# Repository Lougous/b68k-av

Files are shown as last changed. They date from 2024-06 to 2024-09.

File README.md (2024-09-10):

# Overview

This board provides audio and video capabilities to the b68k computer. Main components:
* CPLD for local bus decoding and FPGA configuration
* [flex FPGA](/doc/flex.md)
* SRAM 16-bits, 256kiB or 512 kiB
* video RAMDAC
* OPL2 audio chip

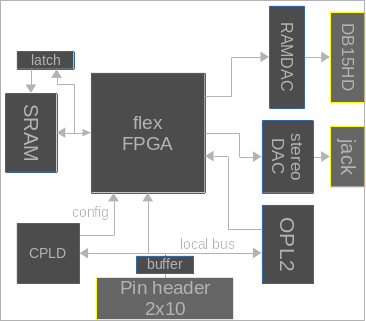
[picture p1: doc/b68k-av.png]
b68k-av block diagram


external interfaces: video (VGA, DIN 15 pins) and audio (3.5mm jack) 

# Memory mapping

The AVMGR CPLD decodes local bus accesses to address itself, the RAMDAC, the OPL2 or the flex FPGA.

| address range | size | memory area |
|:---:|:---:|:-----:|
| 00000h  - 0007Fh  | 128B | AVMGR registers. address bit 0 is ignored |
| 00080h  - 000FFh  | 128B | flex registers |
| 00100h  - 0017Fh  | 128B | RAMDAC registers. address bit 0 is ignored |
| 00180h  - 001FFh  | 128B | OPL2 registers. address bit 0 is ignored |
| 00200h  - 07FFFh  | 512B*63 | mirrors x63 address range 000h-1FFh |
| 08000h -  0FFFFh  | 32kiB | SRAM access (upper 32kiB, banking through flex register) |
| 10000h -  1FFFFh  | 64kiB | SRAM access (banking through flex register) |

## AVMGR registers

These registers provide an interface to configure the flex FPGA. Address bit 0 is ignored, so that odd address target the same register as at even address.

| address offset | name | description |
|:---:|:---:|:-----
| 00000h | cfgnsts | bit 0: (r) flex nSTATUS signal<br>bit 1: (r) flex CONF_DONE signal<br>bit 6: (rw) flex nCONFIG signal<br>bit 7: (rw) flex reset signal (active low) |
| 00002h | dat | bit 0: (rw) flex DAT0 signal<br>When this register is written, the flex DAT0 signal is driven and a pulse is generated on DCLK |
| 00004h | dbg0 | spare register for debug purpose |
| 00006h | dbg1 | spare register for debug purpose |

These registers mirror every 8 bytes.

## OPL2 registers

Provide access to the 2 OPL2 registers. Address bit 0 is ignored, so that odd address target the same register as at even address.

| address offset | name | description |
|:---:|:---:|:-----
| 00000h | regad | OPL2 Address (write) and status (read) register |
| 00002h | regdt | OPL2 Data register |

## RAMDAC registers

Provide access to the RAMDAC registers (Bt476 / IMS G176 or compatible). Address bit 0 is ignored, so that odd address target the same register as at even address.

| address offset | name | description |
|:---:|:---:|:-----
| 00000h | ad_write | Address Register (RAM Write Mode) |
| 00002h | color | Color Palette RAM |
| 00004h | mask | Pixel read Mask Register |
| 00006h | ad_read | Address Register (RAM Read Mode) |

## flex registers

See [flex FPGA](/doc/flex.md) documentation.

# BOM

| Reference  | Part |
|:---:|:---:|
| RN1 | not populated |
| U1 | 74F245 |
| U2 | EPM7064SLC44-10 |
| U3 | MPC6002 |
| U4 | LM337 |
| U6 | EPF10K10LC84-4 |
| U7, U8 | 74F373 |
| U11 | YM3812 (OPL2) |
| U12 | KDA0476BCN-66 |
| D5 | BAT48 (shottky) |
| X1 or X3 | 25-MHz |

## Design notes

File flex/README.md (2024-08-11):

### tools
The latest Quartus version that supports FLEX devices is 9.0 SP2. Not available for download on intel servers any more, here is a link to archive.org:
https://archive.org/details/90sp-2-quartus-free_202310

On linux, depending on distribution/version the use with wine is uncertain ... sometimes quartus can install and run properly, sometimes intall freezes at final stage and GUI cannot run. So far compilation is still possible with command line - see flow.sh script

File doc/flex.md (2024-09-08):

The flex FPGA architecture is depicted hereafter:
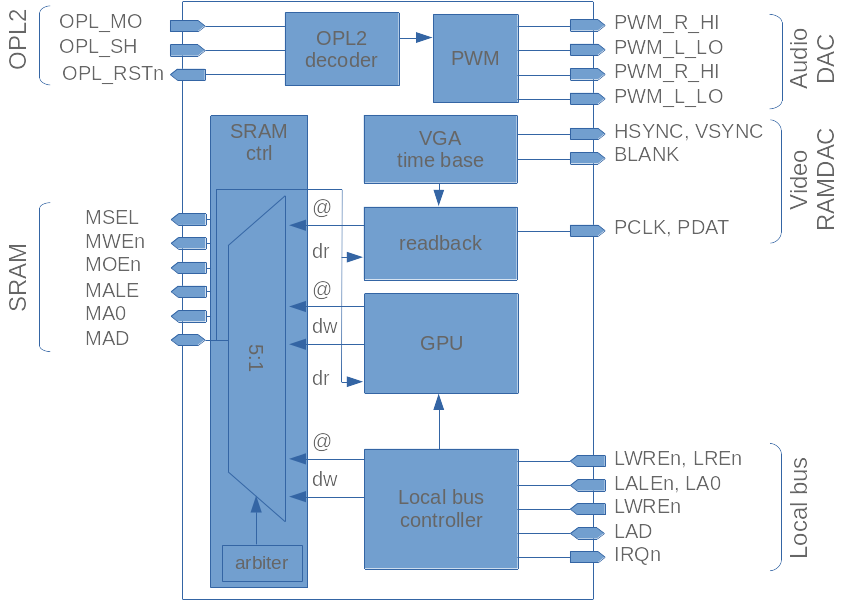
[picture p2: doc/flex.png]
flex FPGA block diagram


# local bus

## Read operations

All read accesses access a single status register:

| address offset | name | description |
|:---:|:---:|:-----:|
| any | status | bit 0: interrupt enable (active high)<br>bit 1: pending interrupt (active high)<br>bits 6..4: SRAM bank (8 banks x 64kiB = 512kiB)<br>7: GPU busy (active high) |

## Write operations (registers)

| address offset | name | description |
|:---:|:---:|:-----:|
| 00080h | itcgf  | bit 0: interrupt enable (active high)<br>bit 1: pending interrupt acknowlege (when written as 1) |
| 00081h | bank | bits 6..4: SRAM access bank (8 banks x 64kiB = 512kiB) |
| 00082h | - | spare |
| 00083h | - | spare |
| 00084h | gpu0 | stop current buffer execution, if so, then set GPU command buffer address bits 8..1 |
| 00085h | gpu1 | set GPU command buffer address bits 16..9, then start command buffer execution |
| 00086h | - | spare |
| 00087h | - | spare |

## Write operations (SRAM)

Write access to SRAM is controlled by the ''bank'' register, that defines which 64kiB section of the SRAM targets the write access into the address ranges listed below:

| address range | size | memory area |
|:---:|:---:|:-----:|
| 08000h -  0FFFFh  | 32kiB  | SRAM access (upper 32kiB of current bank) |
| 10000h -  1FFFFh  | 64kiB  | SRAM access (full bank) |

# GPU

The GPU ables to perform basic 2D memory bloc move operations:
* READ operation: from SRAM to internal scratchpad memory (256 bytes, can be split in 4 banks of 64 bytes)
* WRITE operation: from internal scratchpad memory to SRAM.

READ/WRITE operations purpose is to draw 2D sprites. Sprites are 4-bits per pixels; as pixels in frame buffer are 8-bits, each sprite pixel is completed with an additional 4-bit value (that can be changed for each WRITE operation).

The sprite pixel value 0000b may be optionnaly considered as masked (not written).

Each operation can handle block size of 1 to 16 lines by 1 to 16 words wide, though multiple operations can be used to manage bigger sprites.

GPU commands are a list of 16-bits words, stored into lower 128-kiB in SRAM (00000h to 1FFFEh). Buffer must be 16-bits aligned.

To use the GPU, the usual sequence is:
* load/update graphic data to SRAM
* load/update command list in SRAM
* last command in the list must have the S flag to stop properly (see table below)
* start command list execution (registers ''gpu0''/''gpu1'')

GPU commands also able:
* to change the frame buffer address used by the video readback
* to change the frame buffer format used by the video readback
* to synchronize a command to the vertical refresh

<table>
  <thead>
    <tr>
      <th>15</th><th>14</th><th>13</th><th>12</th><th>11</th><th>10</th><th>9</th><th>8</th>
      <th>7</th><th>6</th><th>5</th><th>4</th><th>3</th><th>2</th><th>1</th><th>0</th>
    </tr>
  </thead>
  <tbody>
    <tr>
      <td>0</td><td colspan=15>ADDR(14:0)</td>
    </tr>
    <tr>
      <td>1</td><td>0</td><td>-</td><td colspan=4>ADDR(18:15)</td><td>S</td><td colspan=4>HEIGHT(3:0)</td><td>F</td><td>LR</td><td>LP</td><td>WS</td>
    </tr>
    <tr>
      <td>1</td><td>1</td><td>-</td><td colspan=4>WIDTH(3:0)</td><td>RW</td><td>KY</td><td>-</td><td colspan=2>BK(1:0)</td><td colspan=4>LUT(3:0)</td>
    </tr>
  </tbody>
</table>

* ADDR:   SRAM address to read/write, or to set as frame buffer start address
* S:      stop display list execution when set
* F:      set frame buffer address/attributes when set
* LR:     Low res mode (validated by F)
* LP:     LUT in hi res mode (validated by F)
* WS:     when set with S, wait for next vertical synchro then resume command execution
* HEIGHT: pixel block height (line number, minus 1)
* WIDTH:  pixel block width (word number, minus 1)
* LUT:    pixel byte bits(7:4) for write (4-bits to 8-bits expansion)
* BK:     256 bytes scratchpad start address MSBs (00h, 40h, 80h, C0h)
* KY:     enable transparency during write with color key 0000b
* RW:     transfer direction: 0 for VRAM to scratchpad, 1 for scratchpad to VRAM

# video time base

The video time base generates video timing in respect to VGA video format to sequence the video readback operations.

# video readback

This function reads a frame buffer at a given start address in SRAM and provides pixel to the RAMDAC.

## pixel addressing

The start address may be changed through GPU command, though the new address will be considered at the next start of frame. Any start address in the two pages listed below can be used, but these rules apply:
* during horizontal pixel walk, the address 9 least significant bits only are incremented (within a 512 bytes segment)
* during vertical pixel walk, start address of line N+1 is start address of line N + 512 bytes, but rolls over within the page

These two rules ease the implementation of scrolling frame buffer content in both axis.

| address range | size | memory area |
|:---:|:---:|:-----:|
| 00000h  - 1FFFFh  | 128kiB | not usable for readback |
| 20000h  - 3FFFFh  | 128kiB | page #0 |
| 40000h  - 5FFFFh  | 128kiB | not usable for readback |
| 60000h  - 7FFFFh  | 128kiB | page #1 |

## pixel format

The readback supports 2 modes:
* low resolution mode; pixels are replicated so that an actual resolution of 320x240 pixels is used, yet still with a VGA (640x480) video timing. Each pixel is an 8-bits value that is used as an index into the color lookup table managed by the RAMDAC chip.
* high resolution mode; based on the 320x240x8-bits defined below, each 8-bit pixel is
  * if pixel MSB (bit 7) is set to zero, no change with low resolution mode (except that color index restricts to range 0..127)
  * if pixel MSB (bit 7) is set to one, the pixel is to be considered as a 2x2 pixel tile, thus possibly achieving an actual resolution of 640x480 pixels. Bits 3..0 provide a value for each pixel in the tile; bits 6..4 is used to form the 8-bits color index as detailed hereafter, together with pixel odd/even position over X and Y axis, as well as an additional LP bit (see GPU)

high resolution pixel expansion, upper-left pixel:
<table>
  <thead>
    <tr>
      <th>7</th><th>6</th><th>5</th><th>4</th><th>3</th><th>2</th><th>1</th><th>0</th>
    </tr>
  </thead>
  <tbody>
    <tr>
      <td>1</td><td>LP</td><td colspan=3>bits 6..4</td><td>0</td><td>0</td><td>bit 0</td>
    </tr>
  </tbody>
</table>

high resolution pixel expansion, upper-right pixel:
<table>
  <thead>
    <tr>
      <th>7</th><th>6</th><th>5</th><th>4</th><th>3</th><th>2</th><th>1</th><th>0</th>
    </tr>
  </thead>
  <tbody>
    <tr>
      <td>1</td><td>LP</td><td colspan=3>bits 6..4</td><td>0</td><td>1</td><td>bit 1</td>
    </tr>
  </tbody>
</table>

high resolution pixel expansion, lower-left pixel:
<table>
  <thead>
    <tr>
      <th>7</th><th>6</th><th>5</th><th>4</th><th>3</th><th>2</th><th>1</th><th>0</th>
    </tr>
  </thead>
  <tbody>
    <tr>
      <td>1</td><td>LP</td><td colspan=3>bits 6..4</td><td>1</td><td>0</td><td>bit 2</td>
    </tr>
  </tbody>
</table>

high resolution pixel expansion, lower-right pixel:
<table>
  <thead>
    <tr>
      <th>7</th><th>6</th><th>5</th><th>4</th><th>3</th><th>2</th><th>1</th><th>0</th>
    </tr>
  </thead>
  <tbody>
    <tr>
      <td>1</td><td>LP</td><td colspan=3>bits 6..4</td><td>1</td><td>1</td><td>bit 3</td>
    </tr>
  </tbody>
</table>

# SRAM controller

Grants access to SRAM to (in priority order):
* readback (read only)
* local bus (write only)
* GPU (read / write)

# Audio

The flex FPGA decodes OPL2 output and generates a dual level PWM (6-bits x2, 12-bits precision in total). See ''audio_out_pwm_stereo'' sheet in board schematics for further details.

Both left and right channels output the same (OPL2 is mono).

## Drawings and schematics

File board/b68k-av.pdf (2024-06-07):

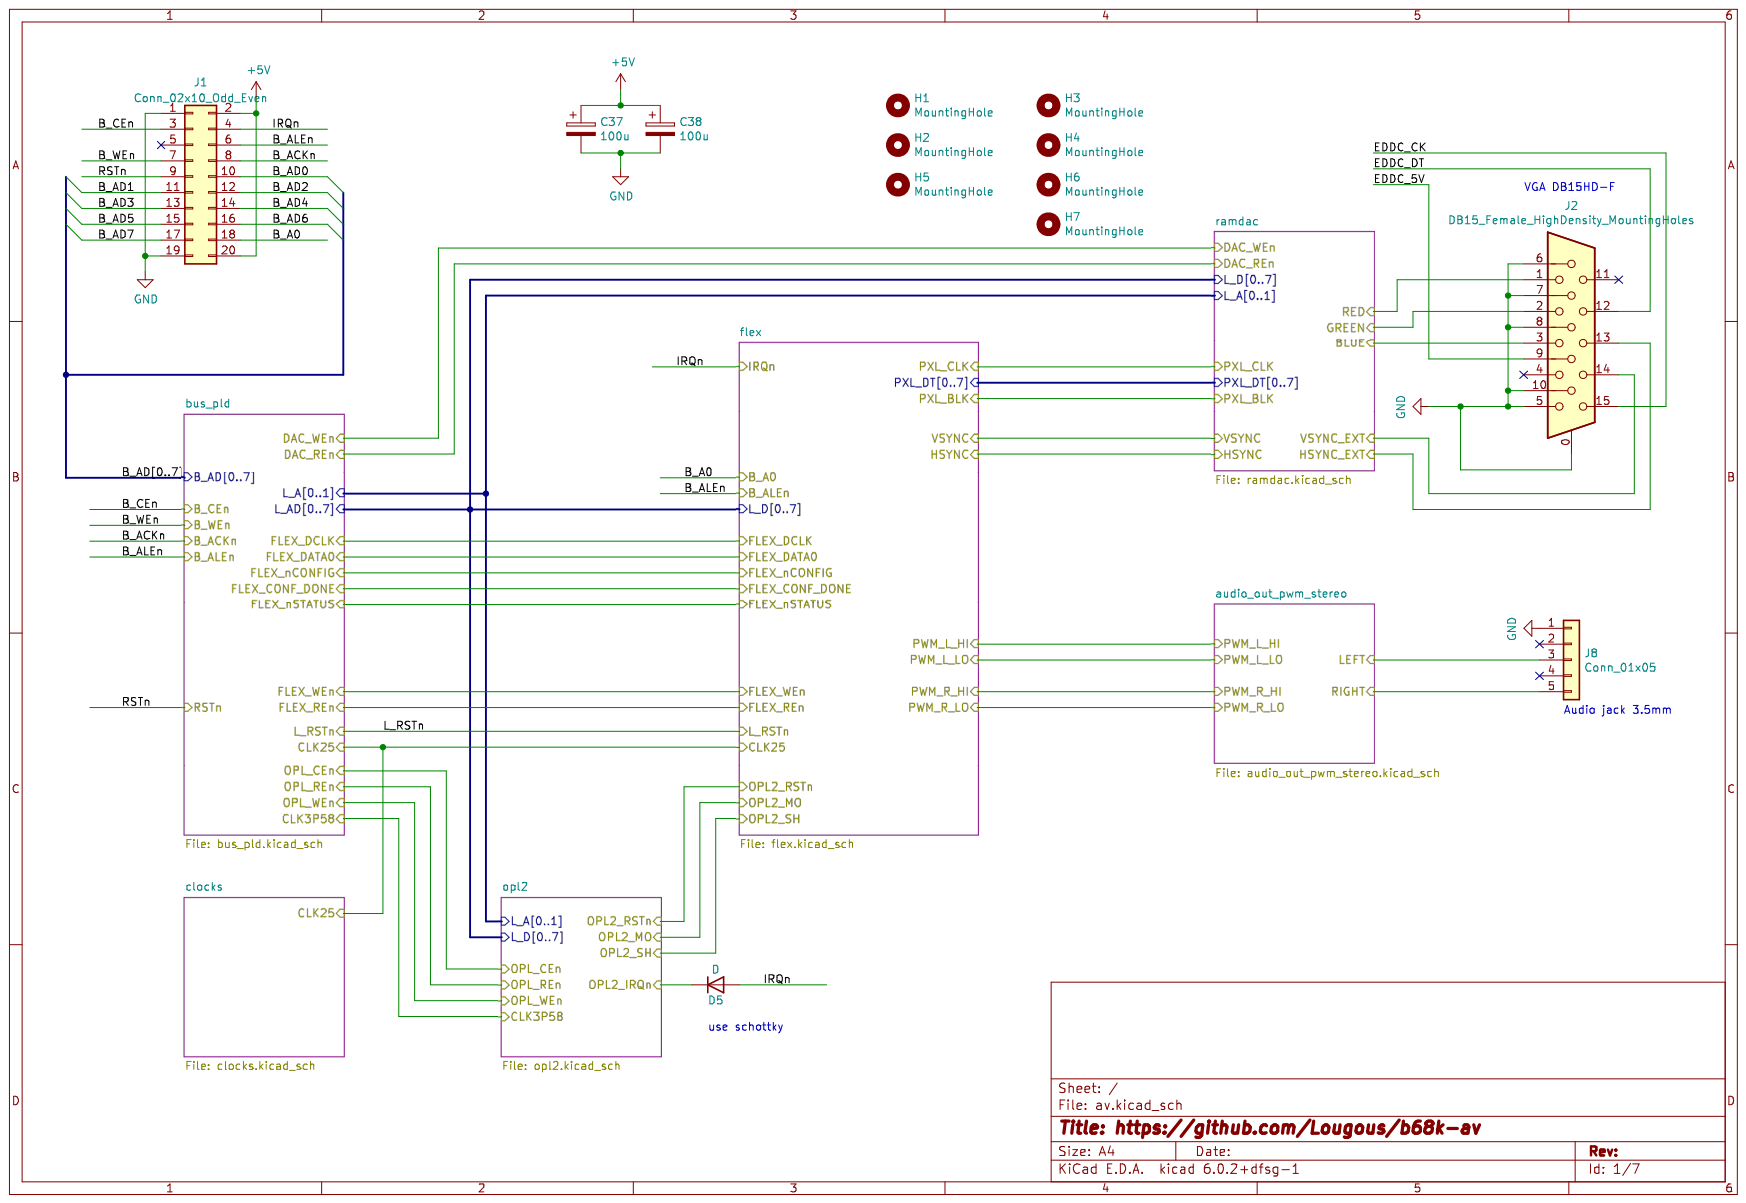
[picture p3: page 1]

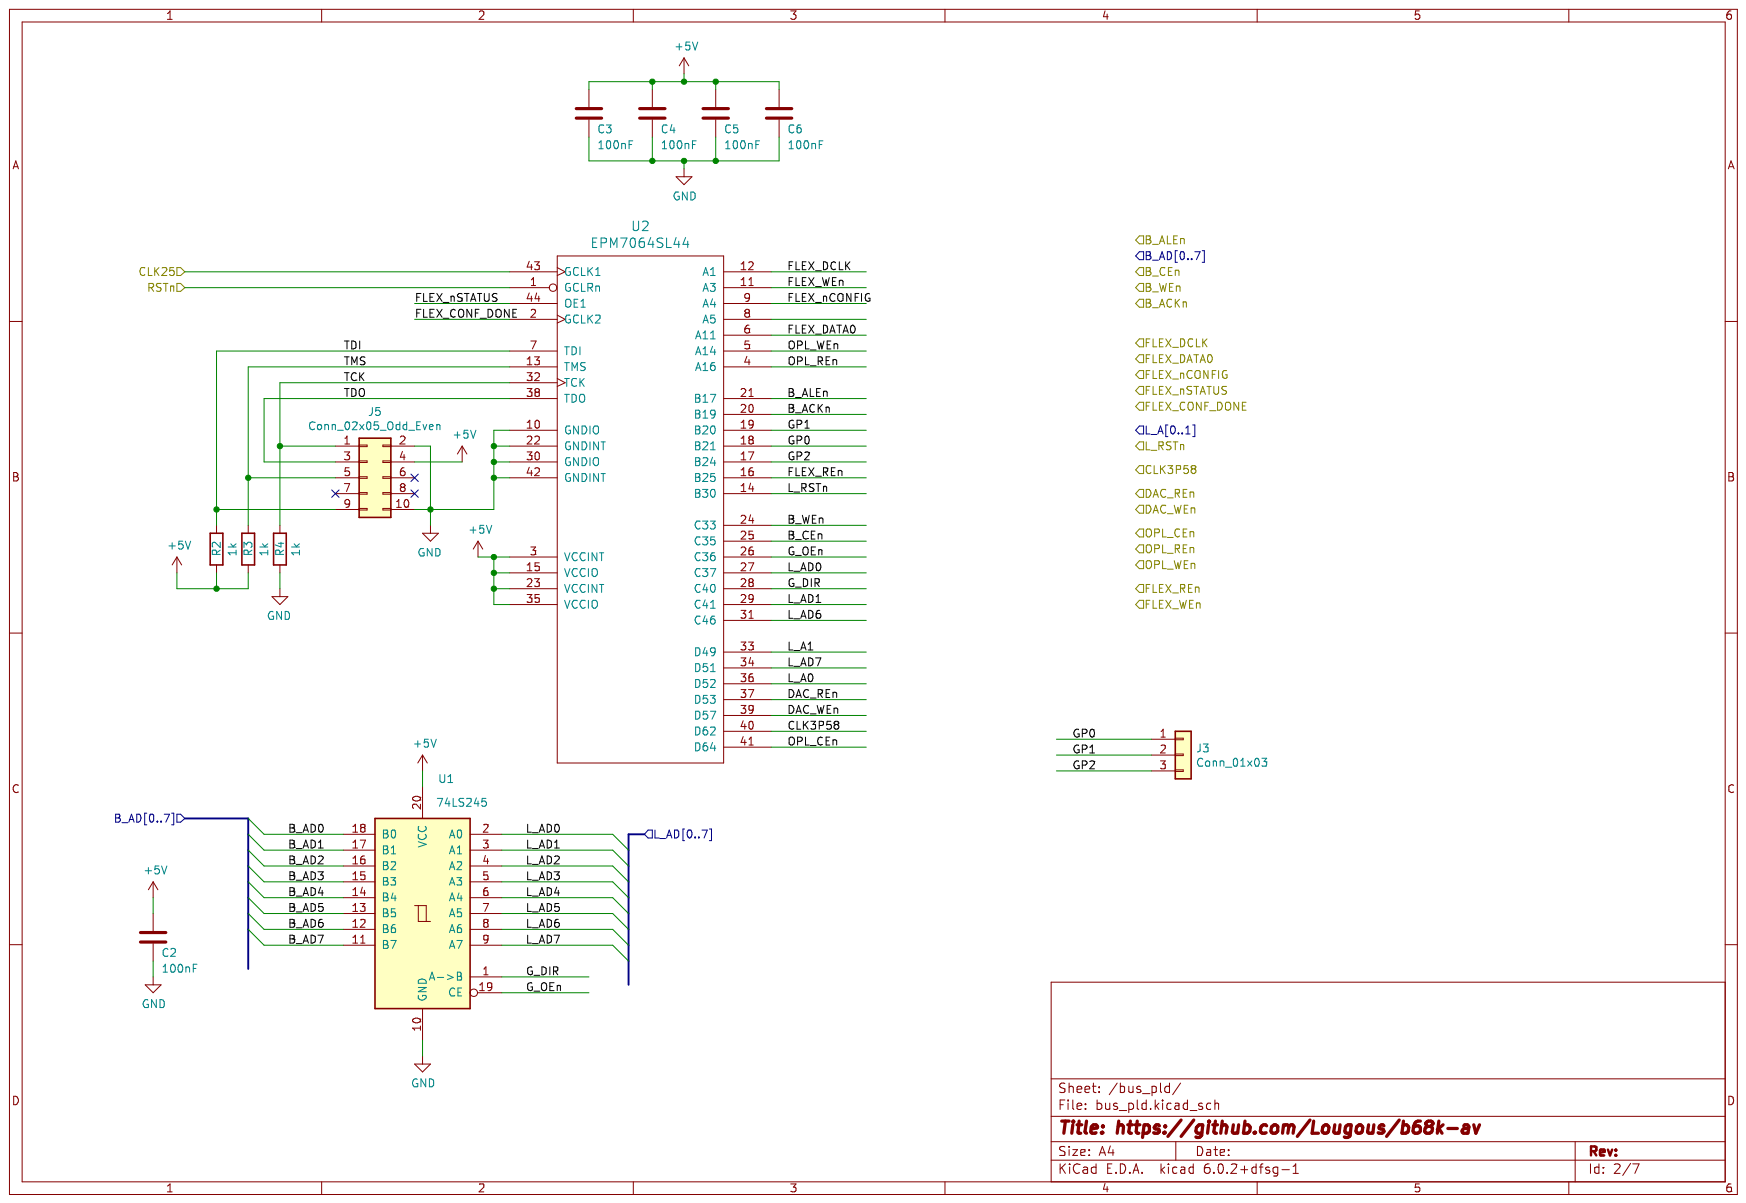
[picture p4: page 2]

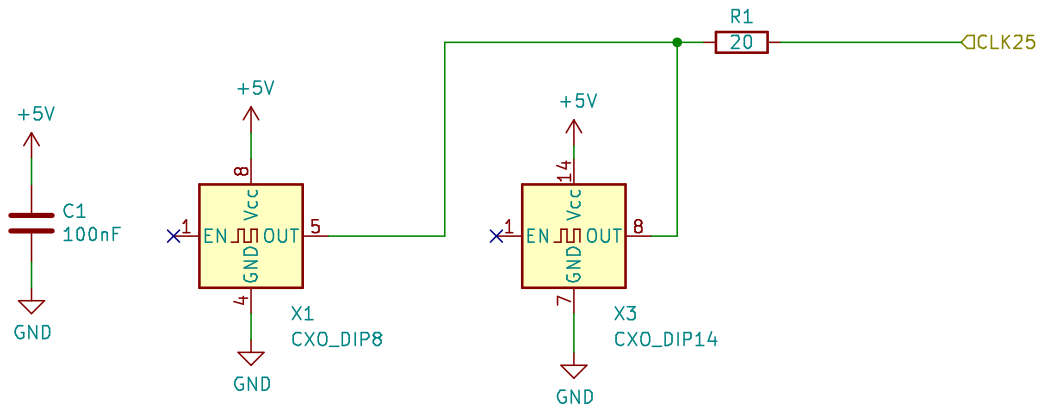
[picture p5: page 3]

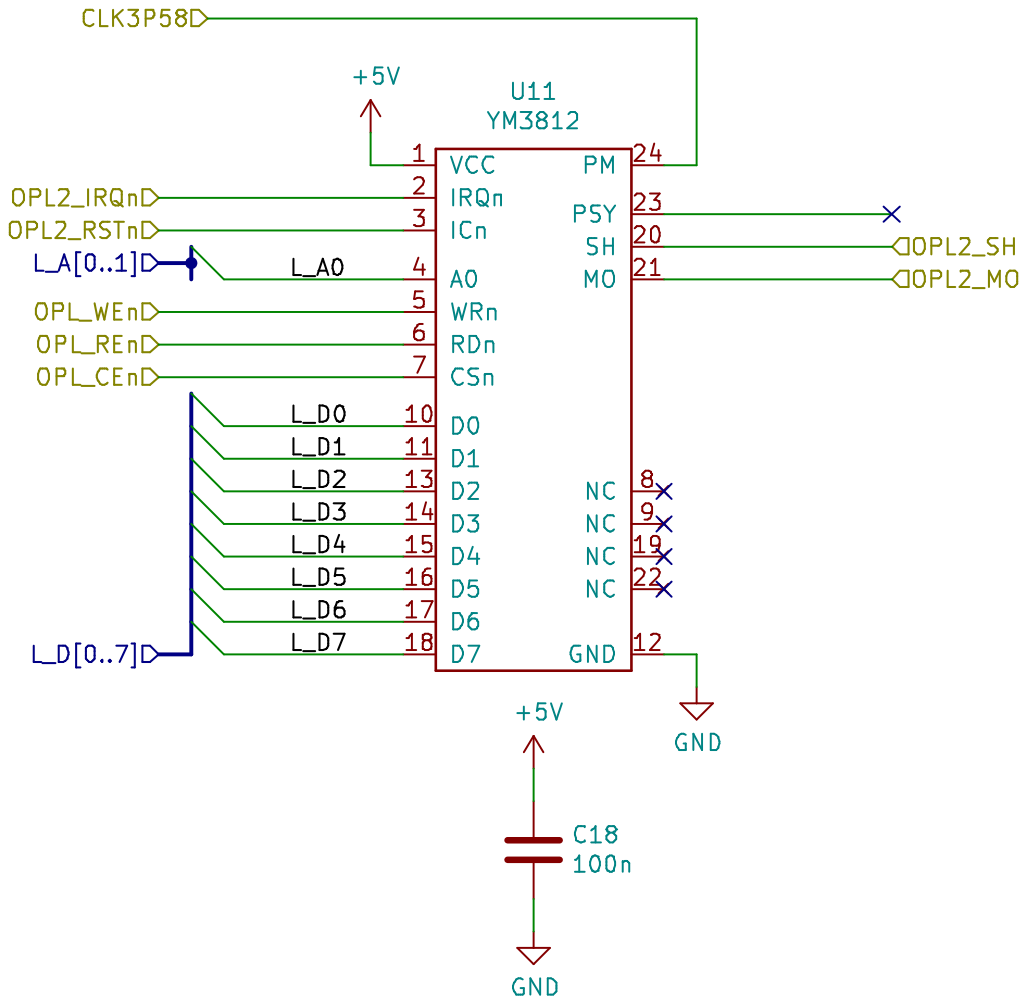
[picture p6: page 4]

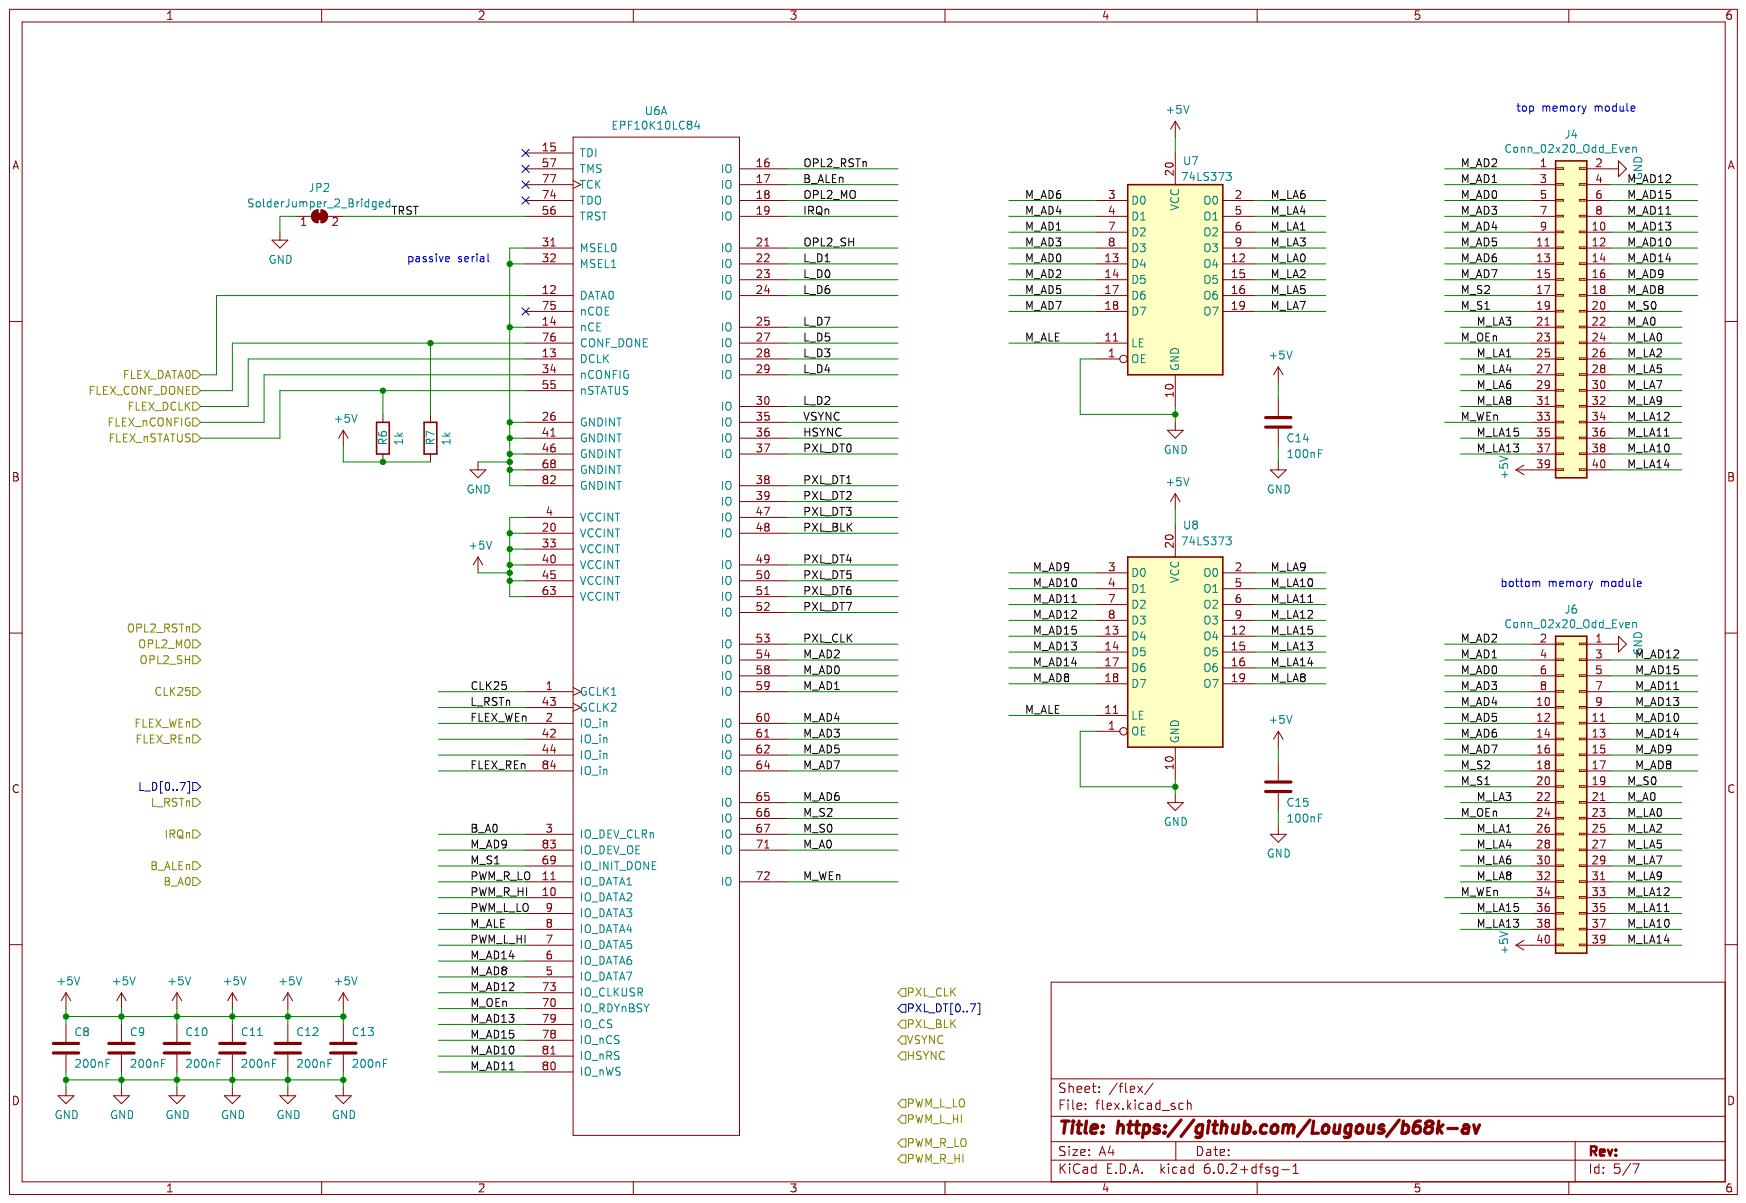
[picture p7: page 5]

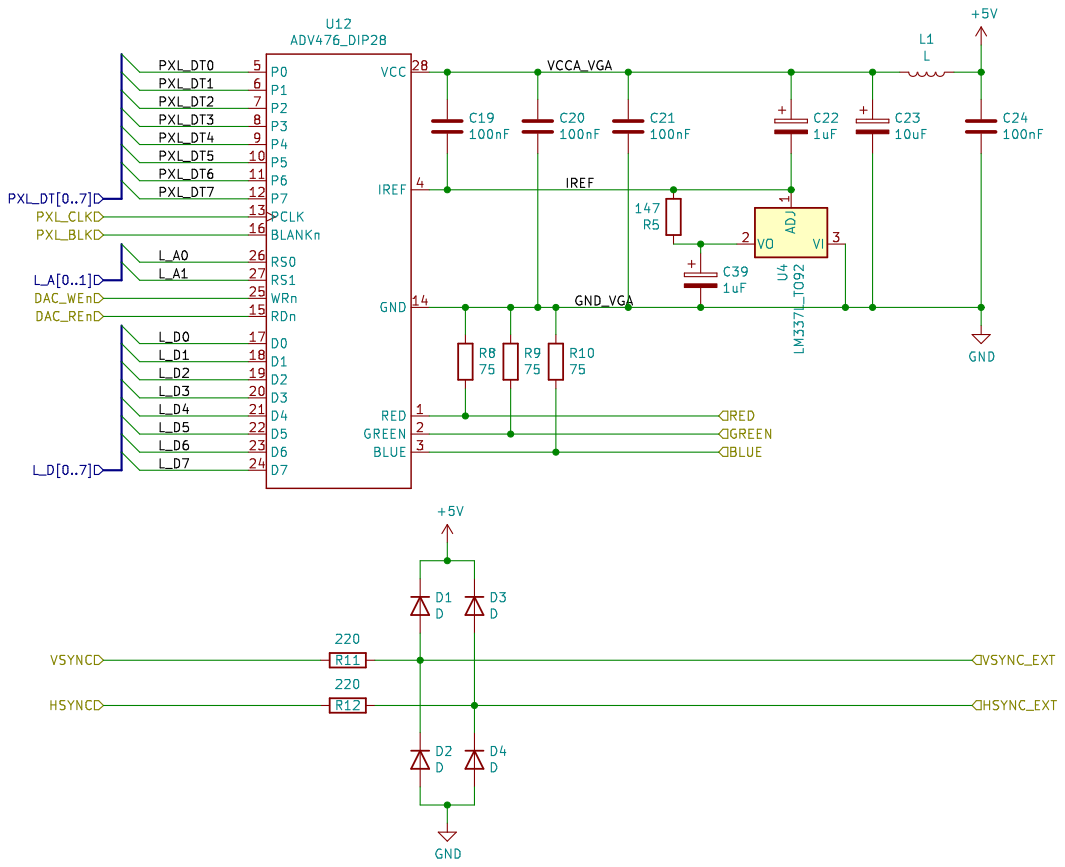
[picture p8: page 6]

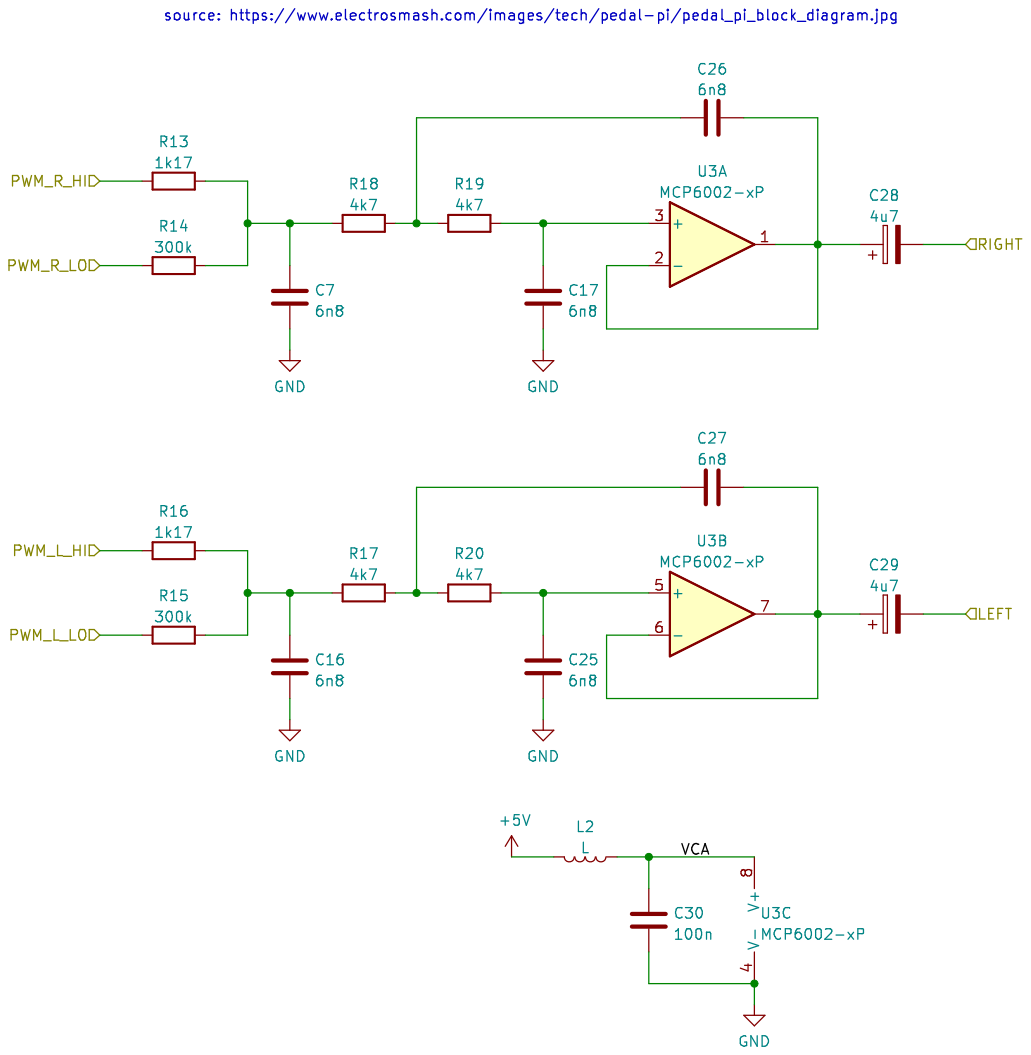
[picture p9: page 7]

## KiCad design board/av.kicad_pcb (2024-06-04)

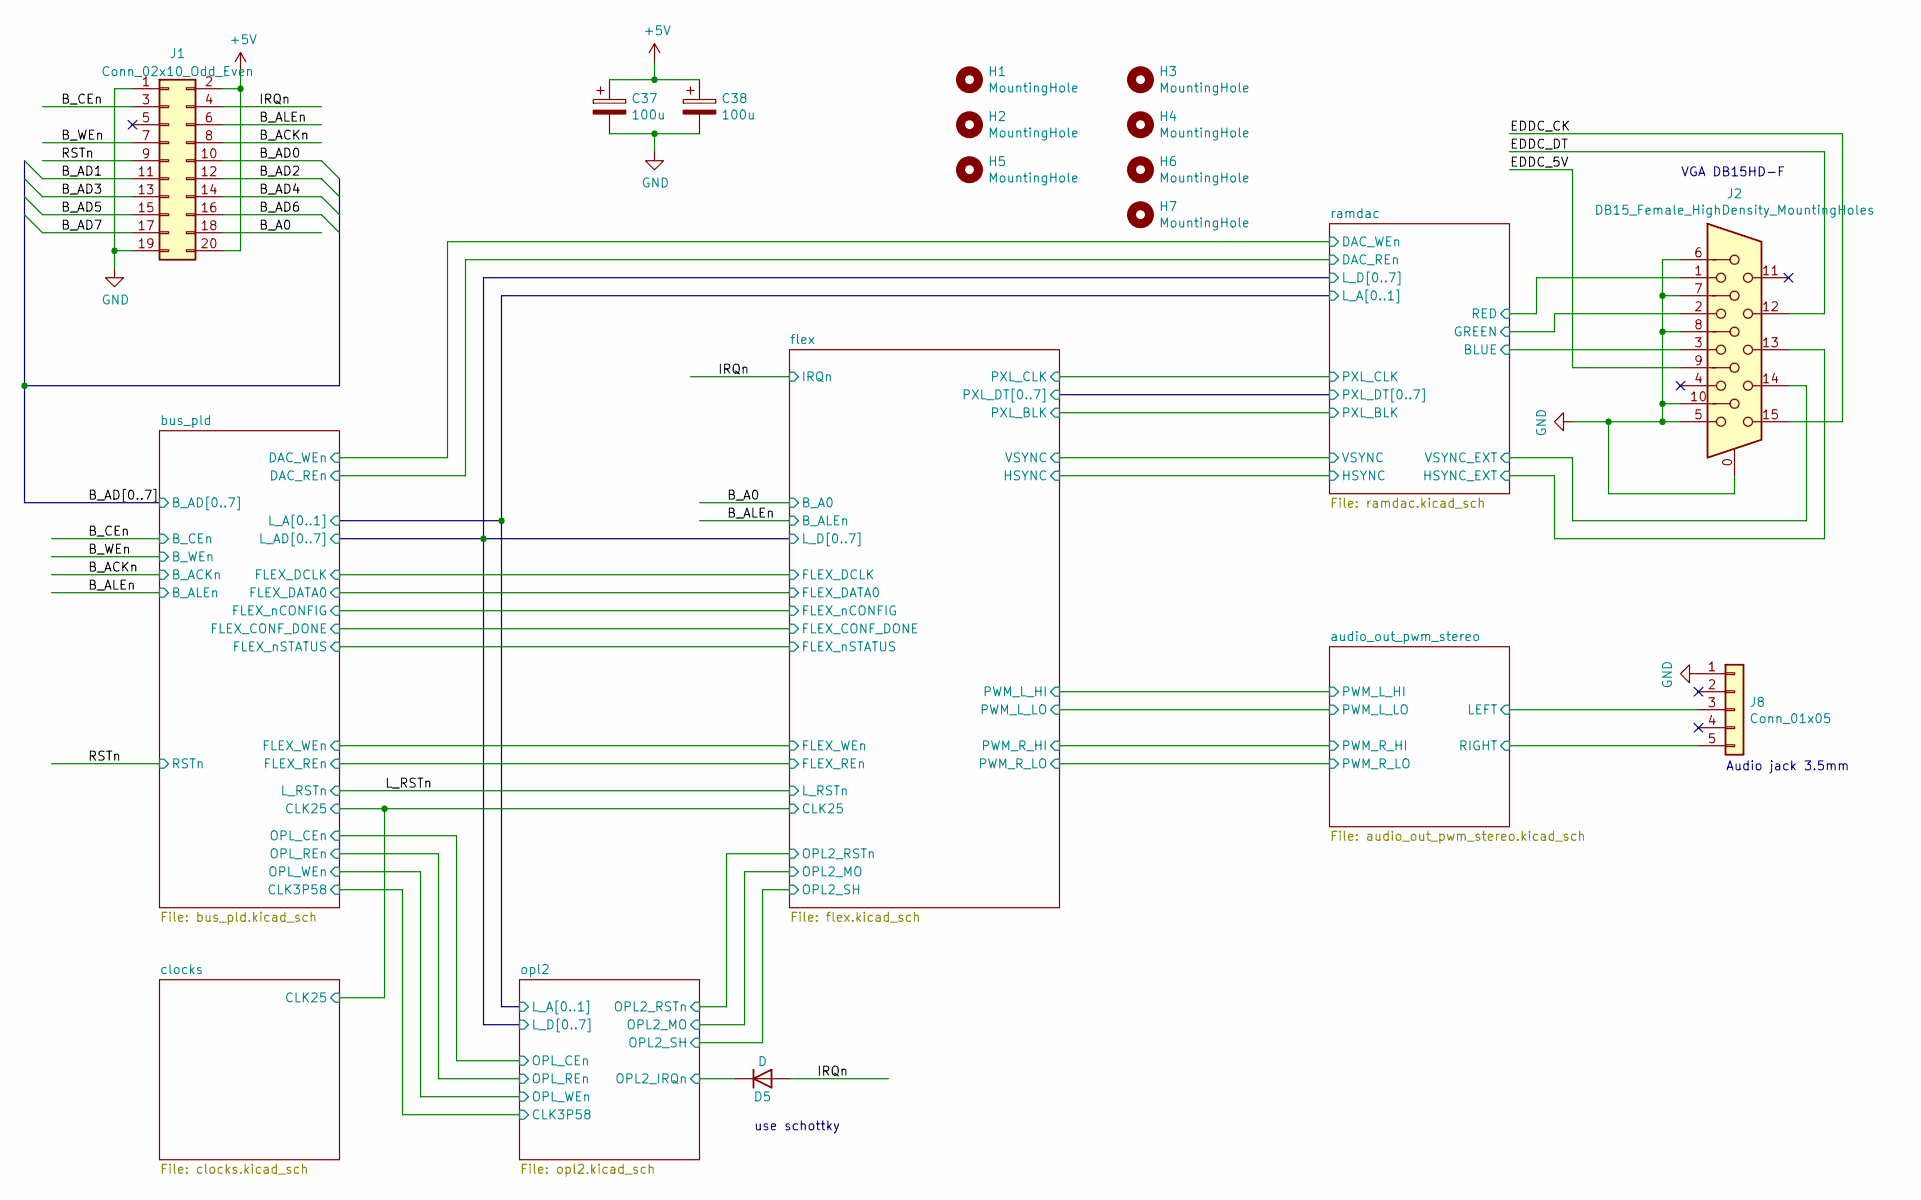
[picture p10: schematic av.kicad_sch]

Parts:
C37, C38: 100u; CP_Radial_D5.0mm_P2.00mm
D5: D; D_DO-34_SOD68_P7.62mm_Horizontal
H1, H2, H3, H4, H5, H6, H7: MountingHole; MountingHole_2.7mm_M2.5_DIN965_Pad
J1: Conn_02x10_Odd_Even; PinHeader_2x10_P2.54mm_Vertical
J2: DB15_Female_HighDensity_MountingHoles; DSUB-15-HD_Female_Horizontal_P2.29x1.98mm_EdgePinOffset3.03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
J8: Conn_01x05; ASJ-5-X_3.5mm_Jack

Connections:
+5V: C37.1, C38.1, J1.2, J1.20; also elsewhere on the board
/B_A0: J1.18; also elsewhere on the board
/B_ACKn: J1.8; also elsewhere on the board
/B_AD0: J1.10; also elsewhere on the board
/B_AD1: J1.11; also elsewhere on the board
/B_AD2: J1.12; also elsewhere on the board
/B_AD3: J1.13; also elsewhere on the board
/B_AD4: J1.14; also elsewhere on the board
/B_AD5: J1.15; also elsewhere on the board
/B_AD6: J1.16; also elsewhere on the board
/B_AD7: J1.17; also elsewhere on the board
/B_ALEn: J1.6; also elsewhere on the board
/B_CEn: J1.3; also elsewhere on the board
/B_WEn: J1.7; also elsewhere on the board
/EDDC_5V: J2.9
/EDDC_CK: J2.15
/EDDC_DT: J2.12
/IRQn: D5.2 (A), J1.4; also elsewhere on the board
/RSTn: J1.9; also elsewhere on the board
/audio_out_pwm_stereo/LEFT: J8.3; also elsewhere on the board
/audio_out_pwm_stereo/RIGHT: J8.5; also elsewhere on the board
/opl2/OPL2_IRQn: D5.1 (K); also elsewhere on the board
/ramdac/BLUE: J2.3; also elsewhere on the board
/ramdac/GREEN: J2.2; also elsewhere on the board
/ramdac/HSYNC_EXT: J2.13; also elsewhere on the board
/ramdac/RED: J2.1; also elsewhere on the board
/ramdac/VSYNC_EXT: J2.14; also elsewhere on the board
GND: C37.2, C38.2, J1.1, J1.19, J2.0, J2.5, J2.6, J2.7, J2.8, J2.10, J8.1; also elsewhere on the board

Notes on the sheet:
Audio jack 3.5mm
use schottky
VGA DB15HD-F

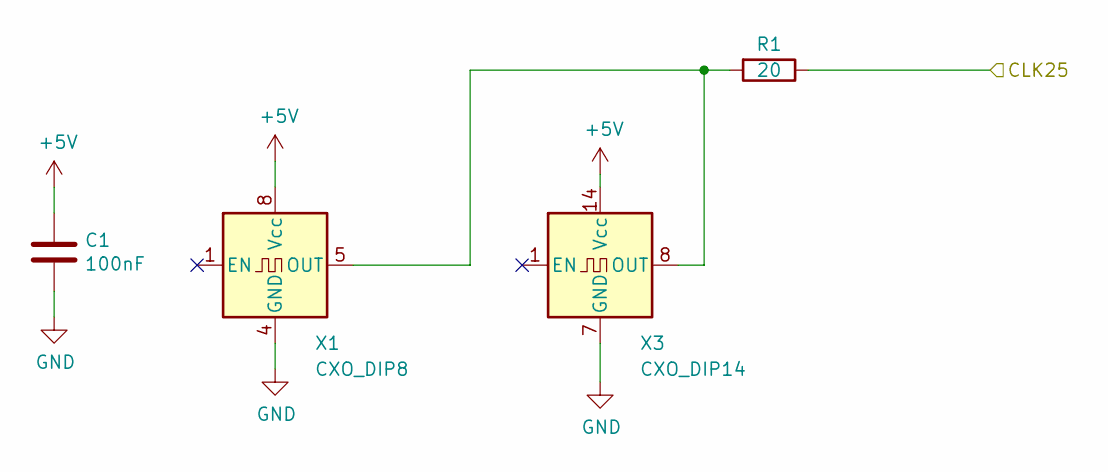
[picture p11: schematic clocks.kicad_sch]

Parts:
C1: 100nF; C_Disc_D4.3mm_W1.9mm_P5.00mm
R1: 20; R_Axial_DIN0204_L3.6mm_D1.6mm_P7.62mm_Horizontal
X1: CXO_DIP8; Oscillator_DIP-8
X3: CXO_DIP14; Oscillator_DIP-14

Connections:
+5V: C1.1, X1.8 (Vcc), X3.14 (Vcc); also elsewhere on the board
/flex/CLK25: R1.1; also elsewhere on the board
GND: C1.2, X1.4 (GND), X3.7 (GND); also elsewhere on the board
unnamed: R1.2, X1.5 (OUT), X3.8 (OUT)

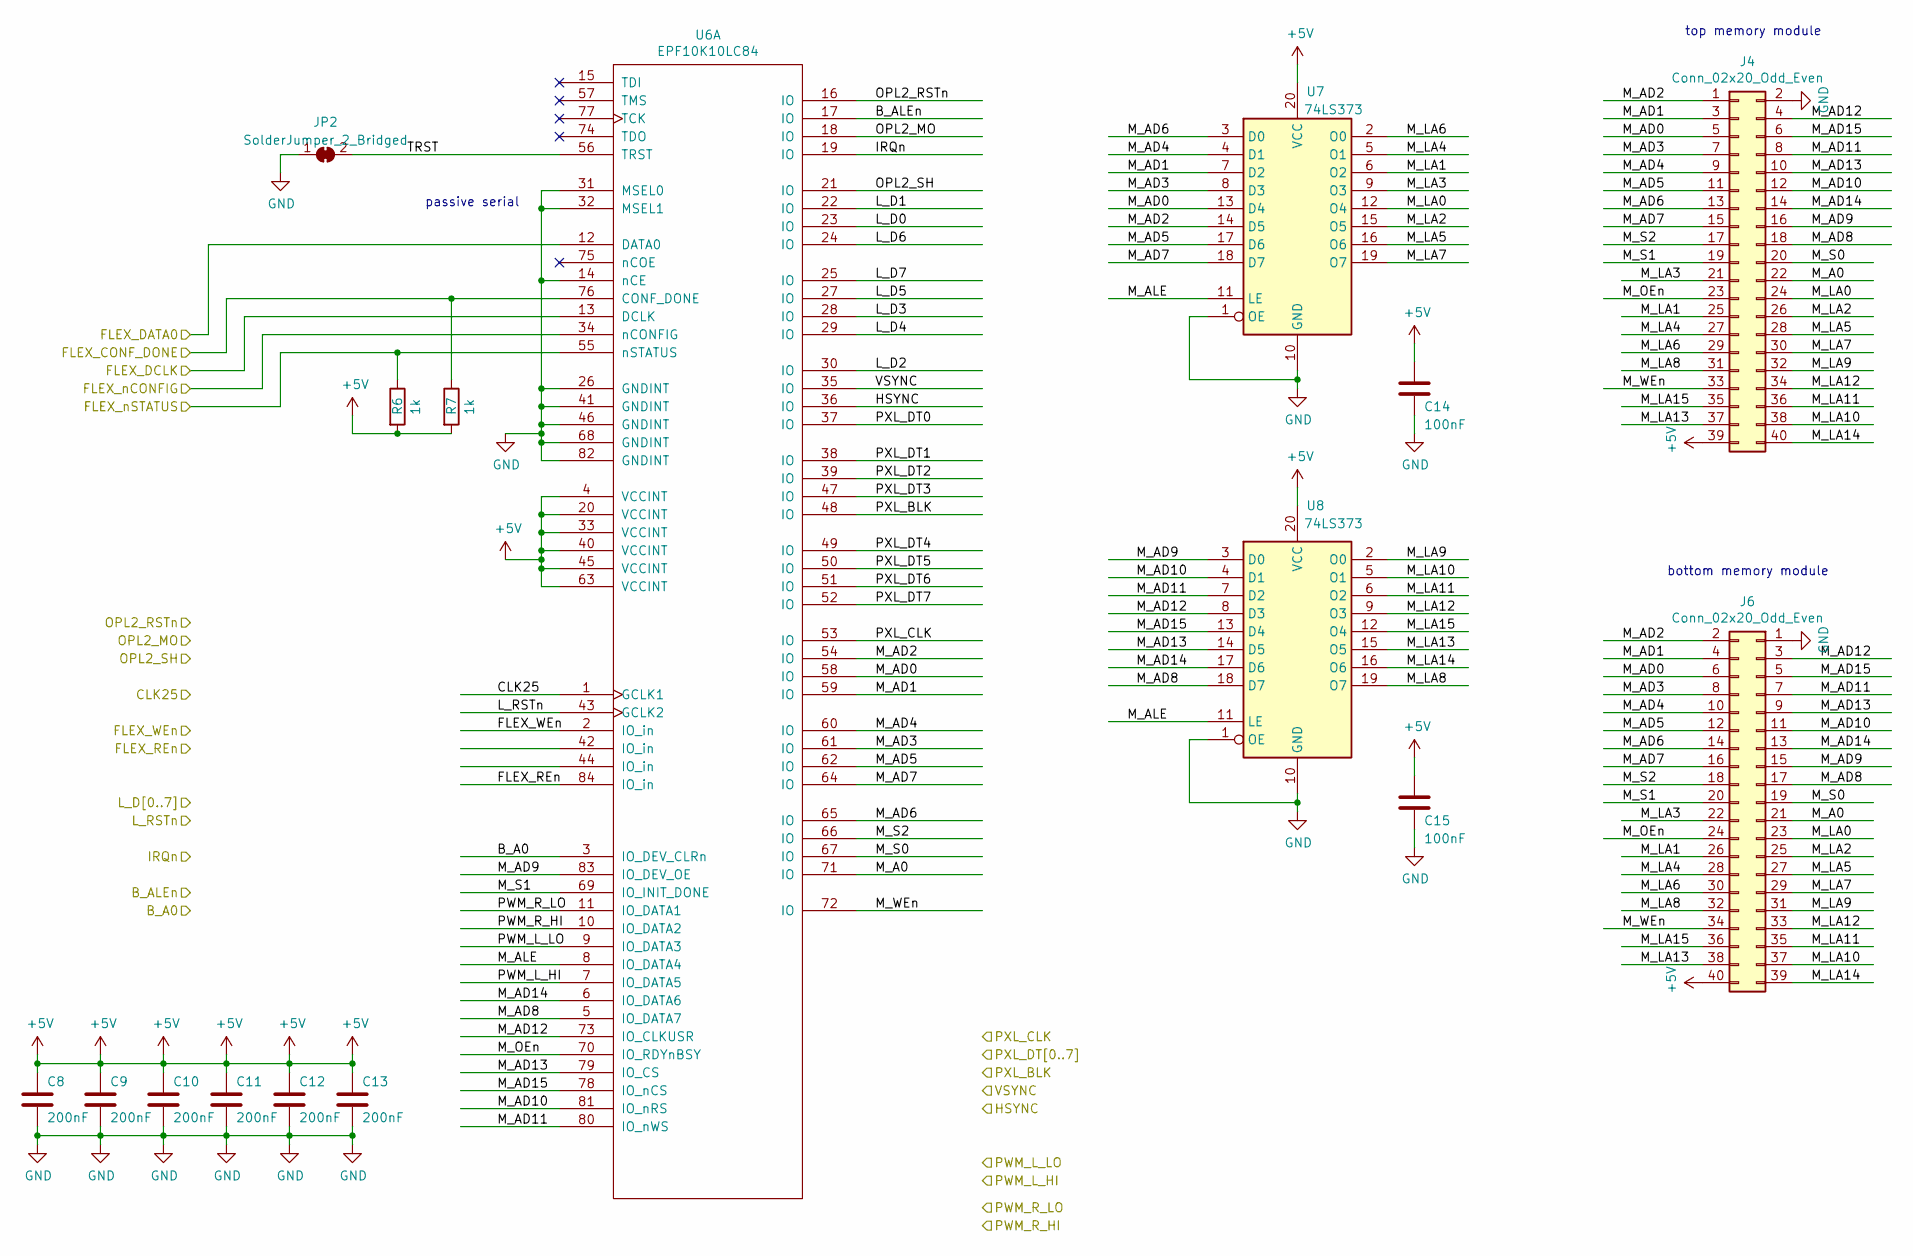
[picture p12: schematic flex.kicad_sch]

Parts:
C8, C9, C10, C11, C12, C13: 200nF; C_Disc_D4.3mm_W1.9mm_P5.00mm
C14, C15: 100nF; C_Disc_D4.3mm_W1.9mm_P5.00mm
J4, J6: Conn_02x20_Odd_Even; PinSocket_2x20_P2.00mm_Vertical_SMD
JP2: SolderJumper_2_Bridged; SolderJumper-2_P1.3mm_Bridged_RoundedPad1.0x1.5mm
R6, R7: 1k; R_Axial_DIN0204_L3.6mm_D1.6mm_P7.62mm_Horizontal
U6: EPF10K10LC84; PLCC-84_THT-Socket
U7, U8: 74LS373; DIP-20_W7.62mm_Socket

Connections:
+5V: C8.1, C9.1, C10.1, C11.1, C12.1, C13.1, C14.1, C15.1, J4.39, J6.40, R6.2, R7.2, U6.4 (VCCINT), U6.20 (VCCINT), U6.33 (VCCINT), U6.40 (VCCINT), U6.45 (VCCINT), U6.63 (VCCINT), U7.20 (VCC), U8.20 (VCC); also elsewhere on the board
/B_A0: U6.3 (IO_DEV_CLRn); also elsewhere on the board
/B_ALEn: U6.17 (IO); also elsewhere on the board
/IRQn: U6.19 (IO); also elsewhere on the board
/L_RSTn: U6.43 (GCLK2); also elsewhere on the board
/bus_pld/FLEX_CONF_DONE: R7.1, U6.76 (CONF_DONE); also elsewhere on the board
/bus_pld/FLEX_DATA0: U6.12 (DATA0); also elsewhere on the board
/bus_pld/FLEX_DCLK: U6.13 (DCLK); also elsewhere on the board
/bus_pld/FLEX_REn: U6.84 (IO_in); also elsewhere on the board
/bus_pld/FLEX_WEn: U6.2 (IO_in); also elsewhere on the board
/bus_pld/FLEX_nCONFIG: U6.34 (nCONFIG); also elsewhere on the board
/bus_pld/FLEX_nSTATUS: R6.1, U6.55 (nSTATUS); also elsewhere on the board
/bus_pld/L_AD0: U6.23 (IO); also elsewhere on the board
/bus_pld/L_AD1: U6.22 (IO); also elsewhere on the board
/bus_pld/L_AD2: U6.30 (IO); also elsewhere on the board
/bus_pld/L_AD3: U6.28 (IO); also elsewhere on the board
/bus_pld/L_AD4: U6.29 (IO); also elsewhere on the board
/bus_pld/L_AD5: U6.27 (IO); also elsewhere on the board
/bus_pld/L_AD6: U6.24 (IO); also elsewhere on the board
/bus_pld/L_AD7: U6.25 (IO); also elsewhere on the board
/flex/CLK25: U6.1 (GCLK1); also elsewhere on the board
/flex/HSYNC: U6.36 (IO); also elsewhere on the board
/flex/M_A0: J4.22, J6.21, U6.71 (IO)
/flex/M_AD0: J4.5, J6.6, U6.58 (IO), U7.13 (D4)
/flex/M_AD1: J4.3, J6.4, U6.59 (IO), U7.7 (D2)
/flex/M_AD2: J4.1, J6.2, U6.54 (IO), U7.14 (D5)
/flex/M_AD3: J4.7, J6.8, U6.61 (IO), U7.8 (D3)
/flex/M_AD4: J4.9, J6.10, U6.60 (IO), U7.4 (D1)
/flex/M_AD5: J4.11, J6.12, U6.62 (IO), U7.17 (D6)
/flex/M_AD6: J4.13, J6.14, U6.65 (IO), U7.3 (D0)
/flex/M_AD7: J4.15, J6.16, U6.64 (IO), U7.18 (D7)
/flex/M_AD8: J4.18, J6.17, U6.5 (IO_DATA7), U8.18 (D7)
/flex/M_AD9: J4.16, J6.15, U6.83 (IO_DEV_OE), U8.3 (D0)
/flex/M_AD10: J4.12, J6.11, U6.81 (IO_nRS), U8.4 (D1)
/flex/M_AD11: J4.8, J6.7, U6.80 (IO_nWS), U8.7 (D2)
/flex/M_AD12: J4.4, J6.3, U6.73 (IO_CLKUSR), U8.8 (D3)
/flex/M_AD13: J4.10, J6.9, U6.79 (IO_CS), U8.14 (D5)
/flex/M_AD14: J4.14, J6.13, U6.6 (IO_DATA6), U8.17 (D6)
/flex/M_AD15: J4.6, J6.5, U6.78 (IO_nCS), U8.13 (D4)
/flex/M_ALE: U6.8 (IO_DATA4), U7.11 (LE), U8.11 (LE)
/flex/M_LA0: J4.24, J6.23, U7.12 (O4)
/flex/M_LA1: J4.25, J6.26, U7.6 (O2)
/flex/M_LA2: J4.26, J6.25, U7.15 (O5)
/flex/M_LA3: J4.21, J6.22, U7.9 (O3)
/flex/M_LA4: J4.27, J6.28, U7.5 (O1)
/flex/M_LA5: J4.28, J6.27, U7.16 (O6)
/flex/M_LA6: J4.29, J6.30, U7.2 (O0)
/flex/M_LA7: J4.30, J6.29, U7.19 (O7)
/flex/M_LA8: J4.31, J6.32, U8.19 (O7)
/flex/M_LA9: J4.32, J6.31, U8.2 (O0)
/flex/M_LA10: J4.38, J6.37, U8.5 (O1)
/flex/M_LA11: J4.36, J6.35, U8.6 (O2)
/flex/M_LA12: J4.34, J6.33, U8.9 (O3)
/flex/M_LA13: J4.37, J6.38, U8.15 (O5)
/flex/M_LA14: J4.40, J6.39, U8.16 (O6)
/flex/M_LA15: J4.35, J6.36, U8.12 (O4)
/flex/M_OEn: J4.23, J6.24, U6.70 (IO_RDYnBSY)
/flex/M_S0: J4.20, J6.19, U6.67 (IO)
/flex/M_S1: J4.19, J6.20, U6.69 (IO_INIT_DONE)
/flex/M_S2: J4.17, J6.18, U6.66 (IO)
/flex/M_WEn: J4.33, J6.34, U6.72 (IO)
/flex/OPL2_MO: U6.18 (IO); also elsewhere on the board
/flex/OPL2_RSTn: U6.16 (IO); also elsewhere on the board
/flex/OPL2_SH: U6.21 (IO); also elsewhere on the board
/flex/PWM_L_HI: U6.7 (IO_DATA5); also elsewhere on the board
/flex/PWM_L_LO: U6.9 (IO_DATA3); also elsewhere on the board
/flex/PWM_R_HI: U6.10 (IO_DATA2); also elsewhere on the board
/flex/PWM_R_LO: U6.11 (IO_DATA1); also elsewhere on the board
/flex/PXL_BLK: U6.48 (IO); also elsewhere on the board
/flex/PXL_CLK: U6.53 (IO); also elsewhere on the board
/flex/PXL_DT0: U6.37 (IO); also elsewhere on the board
/flex/PXL_DT1: U6.38 (IO); also elsewhere on the board
/flex/PXL_DT2: U6.39 (IO); also elsewhere on the board
/flex/PXL_DT3: U6.47 (IO); also elsewhere on the board
/flex/PXL_DT4: U6.49 (IO); also elsewhere on the board
/flex/PXL_DT5: U6.50 (IO); also elsewhere on the board
/flex/PXL_DT6: U6.51 (IO); also elsewhere on the board
/flex/PXL_DT7: U6.52 (IO); also elsewhere on the board
/flex/TRST: JP2.2 (B), U6.56 (TRST)
/flex/VSYNC: U6.35 (IO); also elsewhere on the board
GND: C8.2, C9.2, C10.2, C11.2, C12.2, C13.2, C14.2, C15.2, J4.2, J6.1, JP2.1 (A), U6.14 (nCE), U6.26 (GNDINT), U6.31 (MSEL0), U6.32 (MSEL1), U6.41 (GNDINT), U6.46 (GNDINT), U6.68 (GNDINT), U6.82 (GNDINT), U7.1 (OE), U7.10 (GND), U8.1 (OE), U8.10 (GND); also elsewhere on the board

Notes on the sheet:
bottom memory module
passive serial
top memory module

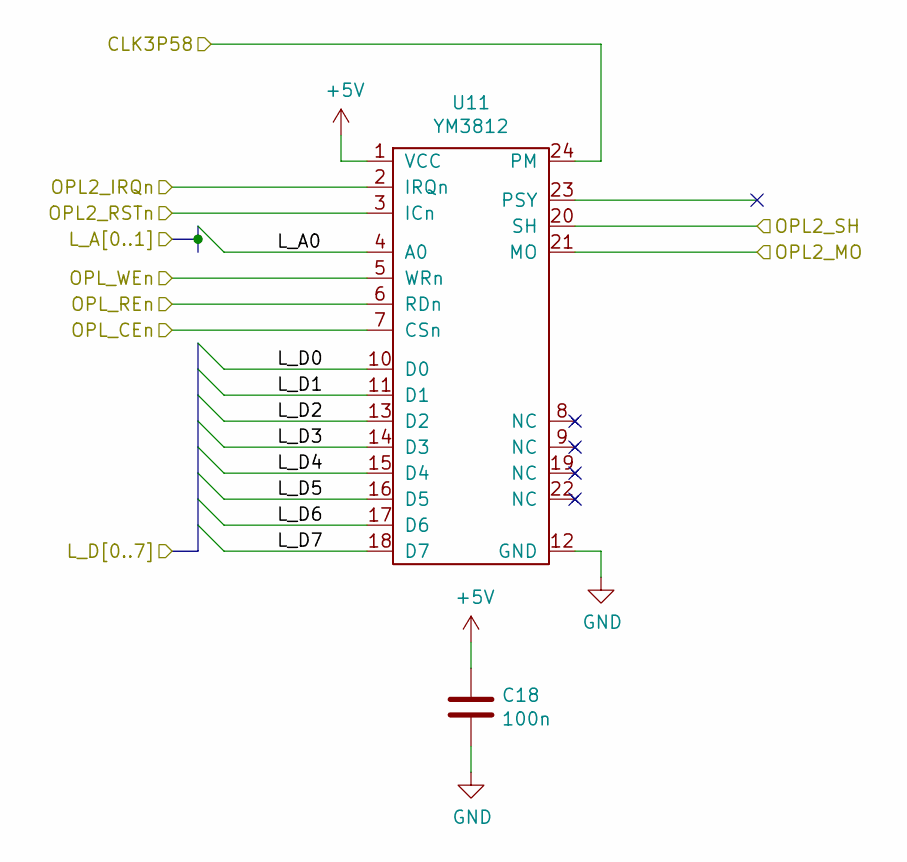
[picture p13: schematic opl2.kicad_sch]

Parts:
C18: 100n; C_Disc_D4.3mm_W1.9mm_P5.00mm
U11: YM3812; DIP-24_W15.24mm_Socket

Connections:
+5V: C18.1, U11.1 (VCC); also elsewhere on the board
/bus_pld/CLK3P58: U11.24 (PM); also elsewhere on the board
/bus_pld/L_A0: U11.4 (A0); also elsewhere on the board
/bus_pld/L_AD0: U11.10 (D0); also elsewhere on the board
/bus_pld/L_AD1: U11.11 (D1); also elsewhere on the board
/bus_pld/L_AD2: U11.13 (D2); also elsewhere on the board
/bus_pld/L_AD3: U11.14 (D3); also elsewhere on the board
/bus_pld/L_AD4: U11.15 (D4); also elsewhere on the board
/bus_pld/L_AD5: U11.16 (D5); also elsewhere on the board
/bus_pld/L_AD6: U11.17 (D6); also elsewhere on the board
/bus_pld/L_AD7: U11.18 (D7); also elsewhere on the board
/bus_pld/OPL_CEn: U11.7 (CSn); also elsewhere on the board
/bus_pld/OPL_REn: U11.6 (RDn); also elsewhere on the board
/bus_pld/OPL_WEn: U11.5 (WRn); also elsewhere on the board
/flex/OPL2_MO: U11.21 (MO); also elsewhere on the board
/flex/OPL2_RSTn: U11.3 (ICn); also elsewhere on the board
/flex/OPL2_SH: U11.20 (SH); also elsewhere on the board
/opl2/OPL2_IRQn: U11.2 (IRQn); also elsewhere on the board
GND: C18.2, U11.12 (GND); also elsewhere on the board

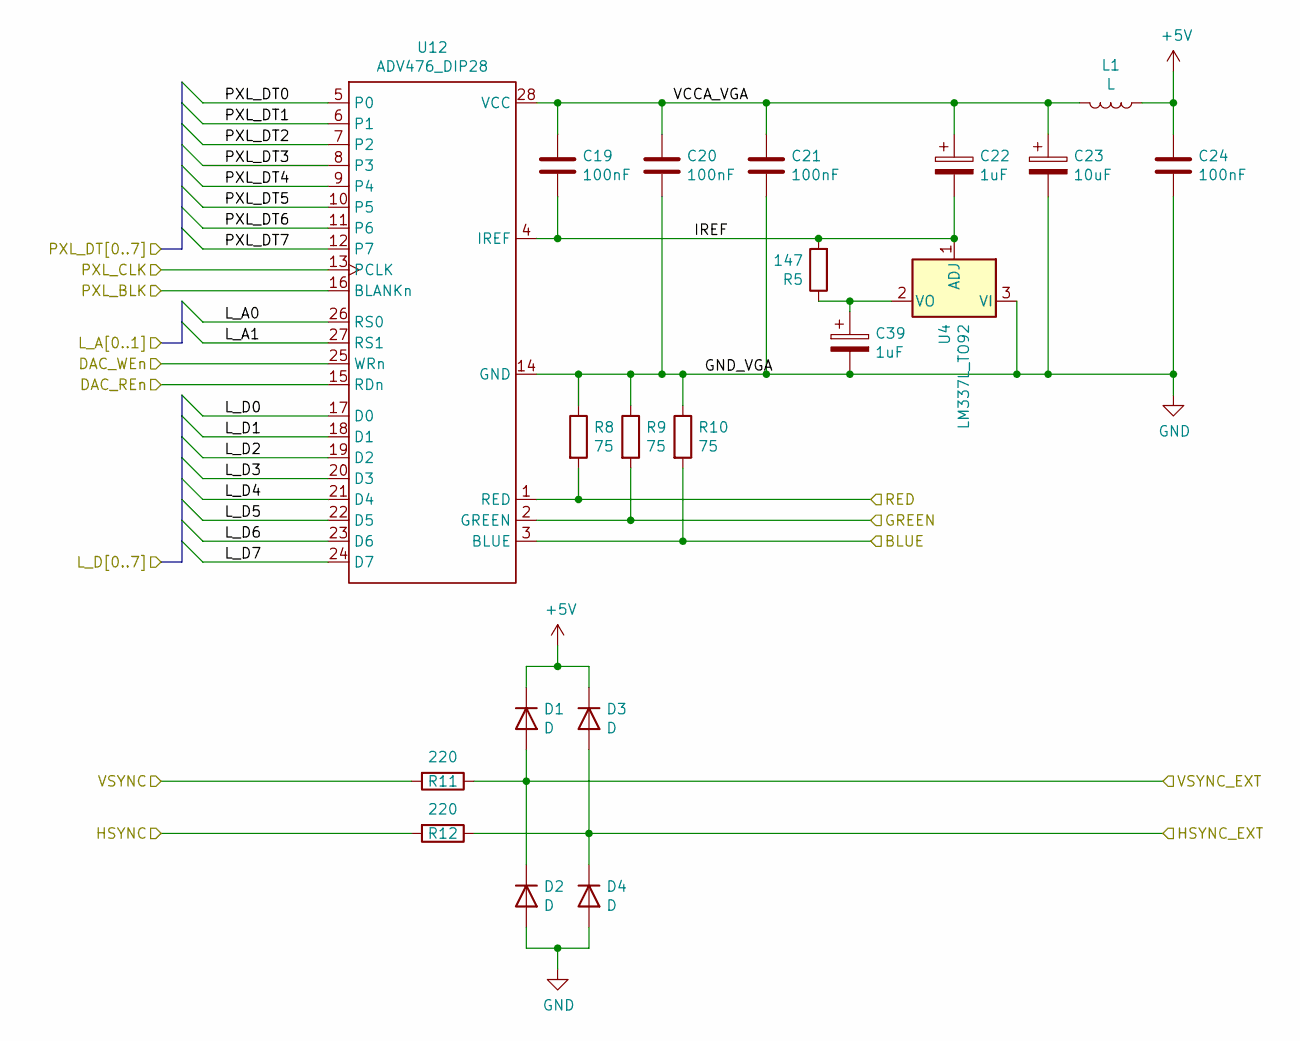
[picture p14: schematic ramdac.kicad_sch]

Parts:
C19, C20, C21, C24: 100nF; C_Disc_D4.3mm_W1.9mm_P5.00mm
C22, C39: 1uF; CP_Radial_Tantal_D4.5mm_P5.00mm
C23: 10uF; CP_Radial_Tantal_D4.5mm_P5.00mm
D1, D2, D3, D4: D; D_DO-34_SOD68_P7.62mm_Horizontal
L1: L; L_Axial_L5.3mm_D2.2mm_P2.54mm_Vertical_Vishay_IM-1
R5: 147; R_Axial_DIN0204_L3.6mm_D1.6mm_P2.54mm_Vertical
R8, R9, R10: 75; R_Axial_DIN0204_L3.6mm_D1.6mm_P7.62mm_Horizontal
R11, R12: 220; R_Axial_DIN0204_L3.6mm_D1.6mm_P7.62mm_Horizontal
U4: LM337L_TO92; TO-92_Inline_Narrow_Oval
U12: ADV476_DIP28; DIP-28_W15.24mm_Socket

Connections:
+5V: C24.1, D1.1 (K), D3.1 (K), L1.1; also elsewhere on the board
/bus_pld/DAC_REn: U12.15 (RDn); also elsewhere on the board
/bus_pld/DAC_WEn: U12.25 (WRn); also elsewhere on the board
/bus_pld/L_A0: U12.26 (RS0); also elsewhere on the board
/bus_pld/L_A1: U12.27 (RS1); also elsewhere on the board
/bus_pld/L_AD0: U12.17 (D0); also elsewhere on the board
/bus_pld/L_AD1: U12.18 (D1); also elsewhere on the board
/bus_pld/L_AD2: U12.19 (D2); also elsewhere on the board
/bus_pld/L_AD3: U12.20 (D3); also elsewhere on the board
/bus_pld/L_AD4: U12.21 (D4); also elsewhere on the board
/bus_pld/L_AD5: U12.22 (D5); also elsewhere on the board
/bus_pld/L_AD6: U12.23 (D6); also elsewhere on the board
/bus_pld/L_AD7: U12.24 (D7); also elsewhere on the board
/flex/HSYNC: R12.2; also elsewhere on the board
/flex/PXL_BLK: U12.16 (BLANKn); also elsewhere on the board
/flex/PXL_CLK: U12.13 (PCLK); also elsewhere on the board
/flex/PXL_DT0: U12.5 (P0); also elsewhere on the board
/flex/PXL_DT1: U12.6 (P1); also elsewhere on the board
/flex/PXL_DT2: U12.7 (P2); also elsewhere on the board
/flex/PXL_DT3: U12.8 (P3); also elsewhere on the board
/flex/PXL_DT4: U12.9 (P4); also elsewhere on the board
/flex/PXL_DT5: U12.10 (P5); also elsewhere on the board
/flex/PXL_DT6: U12.11 (P6); also elsewhere on the board
/flex/PXL_DT7: U12.12 (P7); also elsewhere on the board
/flex/VSYNC: R11.2; also elsewhere on the board
/ramdac/BLUE: R10.2, U12.3 (BLUE); also elsewhere on the board
/ramdac/GREEN: R9.2, U12.2 (GREEN); also elsewhere on the board
/ramdac/HSYNC_EXT: D3.2 (A), D4.1 (K), R12.1; also elsewhere on the board
/ramdac/IREF: C19.2, C22.2, R5.2, U4.1 (ADJ), U12.4 (IREF)
/ramdac/RED: R8.2, U12.1 (RED); also elsewhere on the board
/ramdac/VCCA_VGA: C19.1, C20.1, C21.1, C22.1, C23.1, L1.2, U12.28 (VCC)
/ramdac/VSYNC_EXT: D1.2 (A), D2.1 (K), R11.1; also elsewhere on the board
GND: C20.2, C21.2, C23.2, C24.2, C39.2, D2.2 (A), D4.2 (A), R8.1, R9.1, R10.1, U4.3 (VI), U12.14 (GND); also elsewhere on the board
unnamed: C39.1, R5.1, U4.2 (VO)

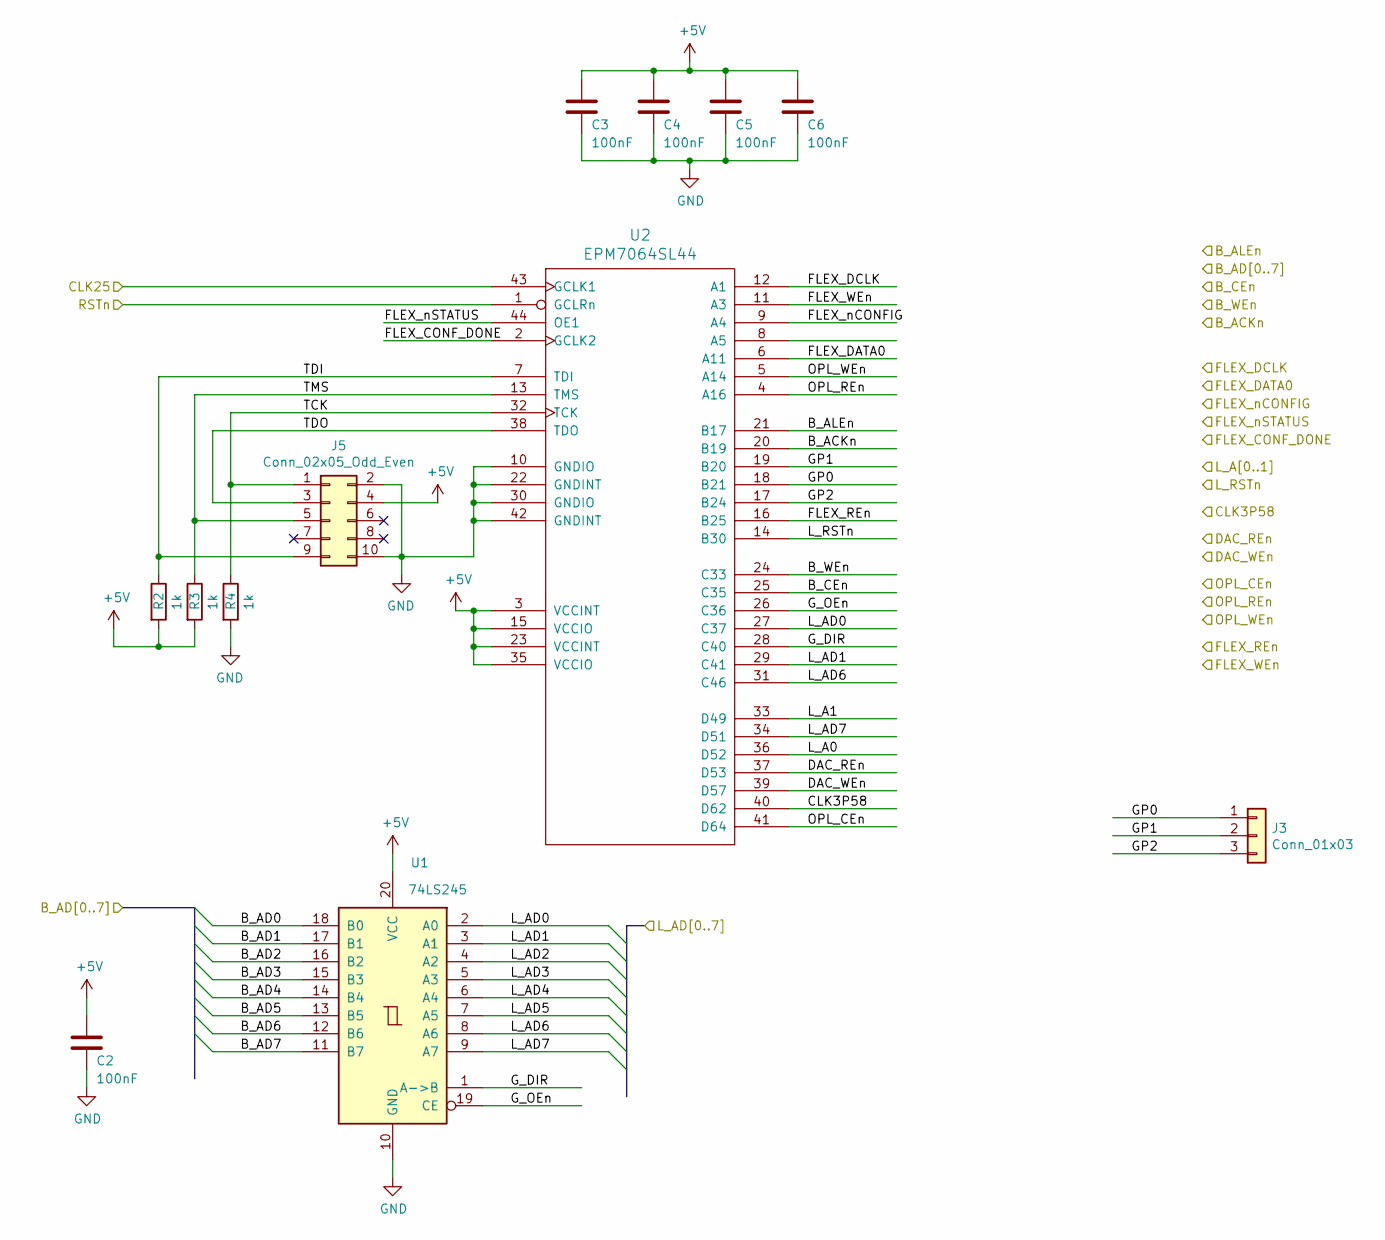
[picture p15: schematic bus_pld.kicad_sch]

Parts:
C2, C3, C4, C5, C6: 100nF; C_Disc_D4.3mm_W1.9mm_P5.00mm
J3: Conn_01x03; PinHeader_1x03_P2.54mm_Vertical
J5: Conn_02x05_Odd_Even; PinHeader_2x05_P2.54mm_Vertical
R2, R3, R4: 1k; R_Axial_DIN0204_L3.6mm_D1.6mm_P7.62mm_Horizontal
U1: 74LS245; DIP-20_W7.62mm_Socket
U2: EPM7064SL44; PLCC-44_THT-Socket

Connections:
+5V: C2.1, C3.1, C4.1, C5.1, C6.1, J5.4, R2.2, R3.2, U1.20 (VCC), U2.3 (VCCINT), U2.15 (VCCIO), U2.23 (VCCINT), U2.35 (VCCIO); also elsewhere on the board
/B_ACKn: U2.20 (B19); also elsewhere on the board
/B_AD0: U1.18 (B0); also elsewhere on the board
/B_AD1: U1.17 (B1); also elsewhere on the board
/B_AD2: U1.16 (B2); also elsewhere on the board
/B_AD3: U1.15 (B3); also elsewhere on the board
/B_AD4: U1.14 (B4); also elsewhere on the board
/B_AD5: U1.13 (B5); also elsewhere on the board
/B_AD6: U1.12 (B6); also elsewhere on the board
/B_AD7: U1.11 (B7); also elsewhere on the board
/B_ALEn: U2.21 (B17); also elsewhere on the board
/B_CEn: U2.25 (C35); also elsewhere on the board
/B_WEn: U2.24 (C33); also elsewhere on the board
/L_RSTn: U2.14 (B30); also elsewhere on the board
/RSTn: U2.1 (GCLRn); also elsewhere on the board
/bus_pld/CLK3P58: U2.40 (D62); also elsewhere on the board
/bus_pld/DAC_REn: U2.37 (D53); also elsewhere on the board
/bus_pld/DAC_WEn: U2.39 (D57); also elsewhere on the board
/bus_pld/FLEX_CONF_DONE: U2.2 (GCLK2); also elsewhere on the board
/bus_pld/FLEX_DATA0: U2.6 (A11); also elsewhere on the board
/bus_pld/FLEX_DCLK: U2.12 (A1); also elsewhere on the board
/bus_pld/FLEX_REn: U2.16 (B25); also elsewhere on the board
/bus_pld/FLEX_WEn: U2.11 (A3); also elsewhere on the board
/bus_pld/FLEX_nCONFIG: U2.9 (A4); also elsewhere on the board
/bus_pld/FLEX_nSTATUS: U2.44 (OE1); also elsewhere on the board
/bus_pld/GP0: J3.1, U2.18 (B21)
/bus_pld/GP1: J3.2, U2.19 (B20)
/bus_pld/GP2: J3.3, U2.17 (B24)
/bus_pld/G_DIR: U1.1 (A->B), U2.28 (C40)
/bus_pld/G_OEn: U1.19 (CE), U2.26 (C36)
/bus_pld/L_A0: U2.36 (D52); also elsewhere on the board
/bus_pld/L_A1: U2.33 (D49); also elsewhere on the board
/bus_pld/L_AD0: U1.2 (A0), U2.27 (C37); also elsewhere on the board
/bus_pld/L_AD1: U1.3 (A1), U2.29 (C41); also elsewhere on the board
/bus_pld/L_AD2: U1.4 (A2); also elsewhere on the board
/bus_pld/L_AD3: U1.5 (A3); also elsewhere on the board
/bus_pld/L_AD4: U1.6 (A4); also elsewhere on the board
/bus_pld/L_AD5: U1.7 (A5); also elsewhere on the board
/bus_pld/L_AD6: U1.8 (A6), U2.31 (C46); also elsewhere on the board
/bus_pld/L_AD7: U1.9 (A7), U2.34 (D51); also elsewhere on the board
/bus_pld/OPL_CEn: U2.41 (D64); also elsewhere on the board
/bus_pld/OPL_REn: U2.4 (A16); also elsewhere on the board
/bus_pld/OPL_WEn: U2.5 (A14); also elsewhere on the board
/bus_pld/TCK: J5.1, R4.1, U2.32 (TCK)
/bus_pld/TDI: J5.9, R2.1, U2.7 (TDI)
/bus_pld/TDO: J5.3, U2.38 (TDO)
/bus_pld/TMS: J5.5, R3.1, U2.13 (TMS)
/flex/CLK25: U2.43 (GCLK1); also elsewhere on the board
GND: C2.2, C3.2, C4.2, C5.2, C6.2, J5.2, J5.10, R4.2, U1.10 (GND), U2.10 (GNDIO), U2.22 (GNDINT), U2.30 (GNDIO), U2.42 (GNDINT); also elsewhere on the board

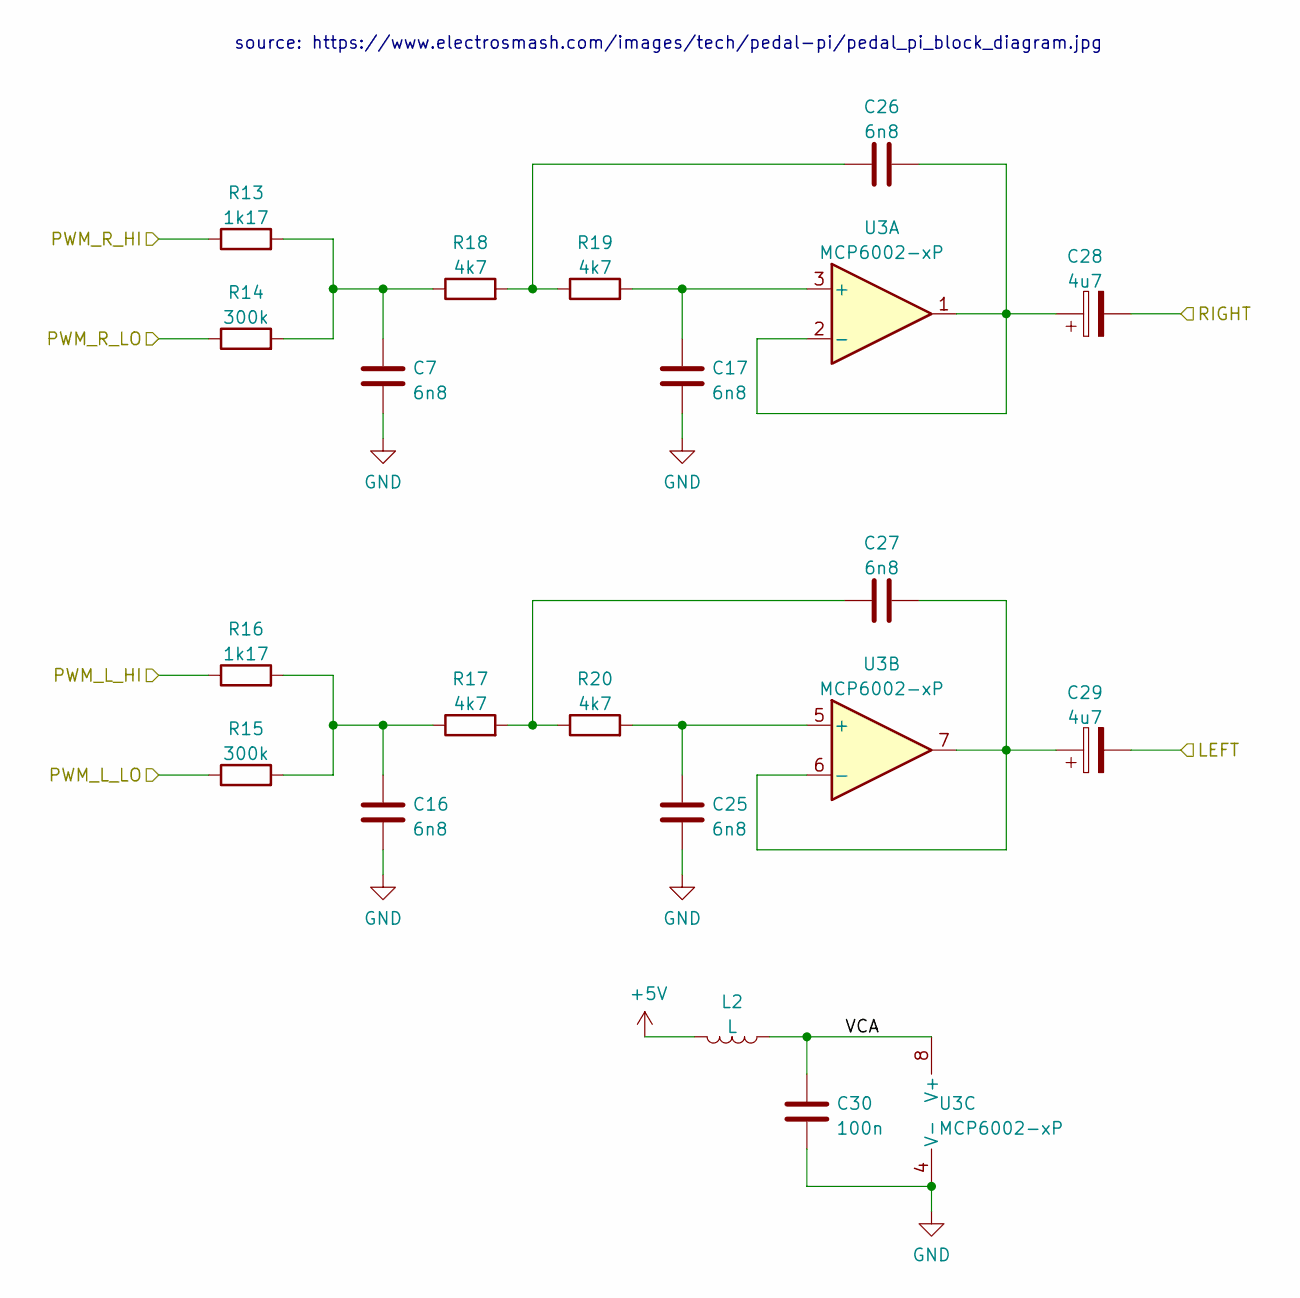
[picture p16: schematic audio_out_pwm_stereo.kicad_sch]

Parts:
C7, C16, C17, C25, C26, C27: 6n8; C_Disc_D4.3mm_W1.9mm_P5.00mm
C28, C29: 4u7; CP_Radial_D5.0mm_P2.00mm
C30: 100n; C_Disc_D4.3mm_W1.9mm_P5.00mm
L2: L; L_Axial_L5.3mm_D2.2mm_P2.54mm_Vertical_Vishay_IM-1
R13, R16: 1k17; R_Axial_DIN0204_L3.6mm_D1.6mm_P7.62mm_Horizontal
R14, R15: 300k; R_Axial_DIN0204_L3.6mm_D1.6mm_P7.62mm_Horizontal
R17, R18, R19, R20: 4k7; R_Axial_DIN0204_L3.6mm_D1.6mm_P7.62mm_Horizontal
U3: MCP6002-xP; DIP-8_W7.62mm_Socket

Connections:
+5V: L2.2; also elsewhere on the board
/audio_out_pwm_stereo/LEFT: C29.2; also elsewhere on the board
/audio_out_pwm_stereo/RIGHT: C28.2; also elsewhere on the board
/audio_out_pwm_stereo/VCA: C30.1, L2.1, U3.8 (V+)
/flex/PWM_L_HI: R16.1; also elsewhere on the board
/flex/PWM_L_LO: R15.1; also elsewhere on the board
/flex/PWM_R_HI: R13.1; also elsewhere on the board
/flex/PWM_R_LO: R14.1; also elsewhere on the board
GND: C7.2, C16.2, C17.2, C25.2, C30.2, U3.4 (V-); also elsewhere on the board
unnamed: C7.1, R13.2, R14.2, R18.1
unnamed: C16.1, R15.2, R16.2, R17.1
unnamed: C17.1, R19.2, U3.3 (+)
unnamed: C25.1, R20.2, U3.5 (+)
unnamed: C26.1, R18.2, R19.1
unnamed: C26.2, C28.1, U3.1, U3.2 (-)
unnamed: C27.1, R17.2, R20.1
unnamed: C27.2, C29.1, U3.6 (-), U3.7

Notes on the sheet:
source: https://www.electrosmash.com/images/tech/pedal-pi/pedal_pi_block_diagram.jpg

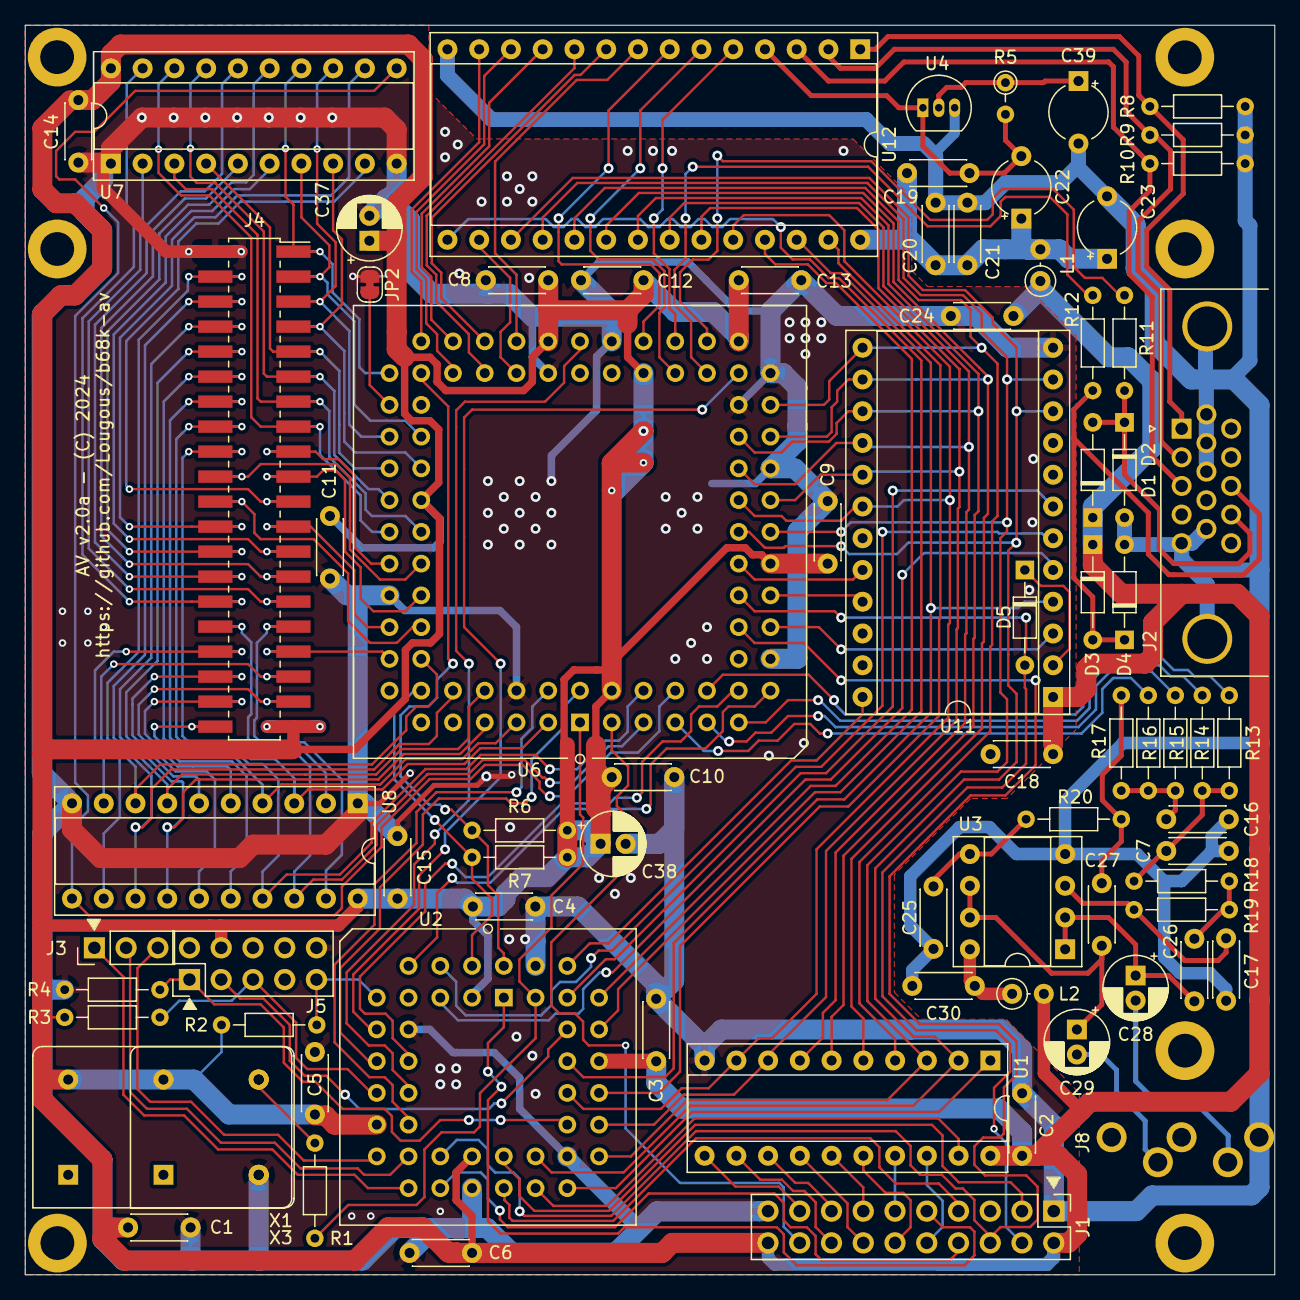
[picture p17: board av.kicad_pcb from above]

Board: 2 copper layers, 100.0 x 100.0 mm, 86 parts (1 on the bottom side), 131 nets.

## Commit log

2024-06-04 import board files
    [audio_out_pwm_stereo.kicad_sch, av.kicad_pcb, av.kicad_sch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]
2024-06-07 add title to schematics
    [audio_out_pwm_stereo.kicad_sch, av.kicad_sch, bus_pld.kicad_sch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]
2024-06-07 export schematics to PDF
2024-06-15 add filter
2024-09-10 add block diagram and BOM

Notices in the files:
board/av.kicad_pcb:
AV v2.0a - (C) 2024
